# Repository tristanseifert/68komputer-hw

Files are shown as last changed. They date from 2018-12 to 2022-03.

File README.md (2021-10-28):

# 68komputer Hardware
Hardware designs for the 68komputer.

You can find the related software [in this repository.](https://github.com/tristanseifert/68komputer-sw)

## Old stuff
The 68008-based design I [wrote about](https://blraaz.me/hardware/2019/11/01/68komputer-it-lives.html) and some other stuff has been moved to the `old` directory. Unfortunately, those designs were done using Cadsoft EAGLE, and I no longer have access to my license for it. There are likely hardware bugs I have no way of fixing. Yay!

## License
The contents of this repo are available under the ISC license.

Previously, the material in the `old` directory was BSD licensed; you can continue to use it under the terms of this license.

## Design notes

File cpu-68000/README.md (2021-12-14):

# 68000 CPU Board
This directory contains the schematic and board files for the main 68komputer CPU board, based around a 68000 operating at up to 10MHz. It combines the processor with 1M of RAM and flash ROM and some additional peripherals.

## Peripherals
In addition to the megabyte of boot ROM and RAM available on the board, the following peripherals are available:

- 32K of battery backed NVRAM, which includes a phantom RTC for time keeping
- An [XR68C681](https://www.maxlinear.com/product/interface/uarts/8-bit-vlio-uarts/xr68c681) DUART, compatible with the "legacy" Motorola 68681 part
- I²C master provided by a [PCF8584](https://www.nxp.com/products/interfaces/ic-spi-serial-interface-devices/ic-bus-controller-and-bridge-ics/ic-bus-controller:PCF8584) controller. It's used to access the I2C bus on the backplane.
- Dual SAA1099 PSG audio chips

## Backplane Interface
The backplane interface is just a buffered copy of the 68k's address and data bus, as well as many of its control signals. The direction of buffers on the CPU board are automatically controlled taking into account external bus masters.

As long as external bus masters properly implement the 68000 bus mastering, they will be entirely transparent. All read/write transactions to peripherals implemented on the CPU board itself will be broadcast on the backplane bus to allow external debugging hardware to capture these accesses.

## Programmable Logic
Many of the logic parts of the system are implemented in 22V10C GALs. See the `logic` directory for these files. They can be assembled using [galette.](https://github.com/simon-frankau/galette)

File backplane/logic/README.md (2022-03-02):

# Backplane Logic Equations
This directory contains the GAL logic equations for the backplane. These are meant to be assembled using [Galette](https://github.com/simon-frankau/galette) assembler.

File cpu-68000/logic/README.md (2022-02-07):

# CPU Board Logic Equations
Here are the GAL logic equations for the CPU board. Filenames map to component names in the rev 2 board/schematic as follows:

- U102: addr_decode.pld
- U305: m68k.pld

** TODO ** It remains to be seen whether most of these logic equations are actually correct; since galette doesn't do parenthesis for grouping of individual components it might all be wrong. Whoops

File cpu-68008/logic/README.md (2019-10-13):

# Logic Files
Source for the GALs on the board is provided in this directory. Below is an overall summary of all signals in the system.

## Inputs
### CPU
- FC[2..0]: Function code
- A[15..19]: Address bus
- !AS: Indicates that the address bus contains a valid address
- R/!W!: Sets the bus direction, valid with !AS

### External Bus
- !BUS_IRQ: External interrupt request
- !BUS_DTACK: Bus data acknowledge

### Peripherals
- !68681_IRQ: DUART interrupt request
- !68681_DTACK: DUART data acknowledge

### Miscellaneous
- RESET: Active high system reset

## Internal Signals
- ADDR_DECODE: Asserted when we're decoding a regular address
	- `!(FC0 & FC1 & FC2) & AS`
- IACK: Asserted when the bus cycle is an interrupt acknowledge
	- `(FC0 & FC1 & FC2) & (A19 & A18 & A17 & A16)`

## Outputs
### CPU
- !VPA: Used to indicate autovectoring in response to IACK
	- `IACK`
- !IPL0/2, !IPL1: Highest priority pending interrupt
- !HALT: Halts the CPU; always asserted with !RESET when RESET is asserted
- !RESET: CPU reset (open drain)
- !BERR: Asserts a bus error if no device asserts DTACK
- !DTACK: Asserts data is ready
	- `68681_DTACK | BUS_DTACK | ROM_CS | RAM_CS | RTC_CS`

### External Bus
- !BUS_CS: Selects the external bus peripherals
	- `ADDR_DECODE & ()`

### Peripherals
- !OE: Output enables for ROM/RAM
	- `!(R/!W!)`
- !68681_IACK: Asserted in response to an interrupt acknowledge for DUART (not used)
- !68681_CS: DUART chip select
	- `ADDR_DECODE & (!A19 & !A18 & A17 & !A17 & !A15)
- !ROM_CS: ROM chip select
	- `ADDR_DECODE & (!A19 & !A18 & !A17)`
- !RAM_CS: RAM chip select
	- `ADDR_DECODE & A19`
- !RTC_CS: NVRAM/RTC chip select
	- `ADDR_DECODE & (!A19 & !A18 & A17 & !A16 & A15)`

### Miscellaneous
- !BERR_TIMER_CLR: Clear signal for bus error timeout generator, this is basically !AS

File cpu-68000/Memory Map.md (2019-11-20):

- $000000 - $0FFFFF: On-Board RAM
	- Remapped as Boot ROM if REMAP is asserted
- $100000 - $7FFFFF: Reserved for RAM expansion
- $800000 - $DFFFFF: Reserved for external peripherals
- $E00000 - $EFFFFF: Boot ROM
- $F00000 - $FFFFFF: Peripherals
	- $F00000 - $F7FFFF: Reserved for external peripherals
	- $FF0000 - $FF7FFF: 68681 (DUART)
	- $FF8000 - $FFFFFF: DS1244 (RTC/NVRAM)

Spaces from $100000 - $DFFFFF and $F00000 - $FEFFFF can be used by expansion connected via SV101. 

**Note:** /DTACK is provided only for addresses decoded internally, e.g. peripherals must provide their own /DTACK.

## Boot ROM Remap
Remapping of boot ROM is configured by OP2 (pin 31) of the 68681. When high (the reset state) the ROM will be mapped at the base of the address space. The boot ROM would disable this line, copy the vector table to RAM, which makes this remap completely transparent to programs on the machine.

## Peripherals
External peripherals will typically occupy an entire megabyte of address space to simplify address decoding; these peripherals will receive an additional 64K segment in IO space for configuration registers.

For an external peripheral at address $800000, the first 64K segment from $F00000 - $F0FFFF would be reserved; a peripheral at address $900000 the segment $F10000 - $F1FFFF, and so forth up to $D00000 receiving the segment $F50000 - $F5FFFF. Note that this rule applies only to peripherals that occupy an entire megabyte in the address space.

Peripherals may elect to only occupy IO space, in which case they must stay in the range of $F60000 - $F7FFFF.

### Identification ROMs
The expansion connector contains the /EXT_ID signal on pin 41. When asserted, expansion cards with info ROMs will map their ROMs onto the bus, instead of whatever they normally would.

Such a ROM must be on 32K boundaries, and contain a specific signature for the system to discover it. The ROM must be connected to the low byte (D0..D7) of the data bus, and will be shadowed to the highest area of RAM and run from there.

/EXT_ID is driven by OP6 (pin 29) of the 68681.

### Interrupts
To assert a CPU interrupt, peripherals may assert either /INTA or /INTB lines. Two IRQ lines are provided to reduce the complexity of interrupt handler routines.

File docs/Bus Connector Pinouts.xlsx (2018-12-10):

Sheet: Pinouts
External Bus Interface (68000) |  |  |  | External Bus Interface (68030) |  |  |  | Expansion Card Interface
Column | Row A | Row B | Row C | Column | Row A | Row B | Row C | Column | Row A | Row B | Row C
1 | GND | 5V | D0 | 1 | A0 | 5V | D0 | 1 | 3V3 | 3V3 | /RESET
2 | A1 | 5V | D1 | 2 | A1 | 5V | D1 | 2 | 3V3 | 3V3
3 | A2 | 5V | D2 | 3 | A2 | 5V | D2 | 3 | GND | GND | GND
4 | A3 | Reserved | D3 | 4 | A3 | /CBREQ | D3 | 4 | GND | GND | GND
5 | A4 | Reserved | D4 | 5 | A4 | /OCS | D4 | 5
6 | A5 | FC[0] | D5 | 6 | A5 | FC[0] | D5 | 6 | AD[1] | GND | AD[0]
7 | A6 | FC[1] | D6 | 7 | A6 | FC[1] | D6 | 7 | AD[3] | GND | AD[2]
8 | A7 | FC[2] | D7 | 8 | A7 | FC[2] | D7 | 8 | AD[5] | GND | AD[4]
9 | A8 | /BERR | D8 | 9 | A8 | /BERR | D8 | 9 | AD[7] | GND | AD[6]
10 | A9 | /RESET | D9 | 10 | A9 | /RESET | D9 | 10 | AD[9] | GND | AD[8]
11 | A10 | /HALT | D10 | 11 | A10 | /HALT | D10 | 11 | AD[11] | GND | AD[10]
12 | A11 | /VPA | D11 | 12 | A11 | /CBACK | D11 | 12 | AD[13] | GND | AD[12]
13 | A12 | /BR | D12 | 13 | A12 | /BR | D12 | 13 | AD[15] | GND | AD[14]
14 | A13 | /BG | D13 | 14 | A13 | /BG | D13 | 14 | AD[17] | GND | AD[16]
15 | A14 | /BGACK | D14 | 15 | A14 | /BGACK | D14 | 15 | AD[19] | GND | AD[18]
16 | A15 | Reserved | D15 | 16 | A15 | /ECS | D15 | 16 | AD[21] | GND | AD[20]
17 | A16 | /IRQ | D16 | 17 | A16 | /IRQ | D16 | 17 | AD[23] | GND | AD[22]
18 | A17 | Reserved | Reserved | 18 | A17 | /STERM | D17 | 18 | AD[25] | GND | AD[24]
19 | A18 | Reserved | Reserved | 19 | A18 | /RMC | D18 | 19 | AD[27] | GND | AD[26]
20 | A19 | Reserved | Reserved | 20 | A19 | /DS | D19 | 20 | AD[29] | GND | AD[28]
21 | A20 | /AS | Reserved | 21 | A20 | /AS | D20 | 21 | AD[31] | GND | AD[30]
22 | A21 | R/W | Reserved | 22 | A21 | R/W | D21 | 22 | GND | GND
23 | A22 | /UDS | Reserved | 23 | A22 | SIZ[0] | D22 | 23 | GND | GND
24 | A23 | /LDS | Reserved | 24 | A23 | SIZ[1] | D23 | 24 |  |  | MODE[0]
25 | GND | GND | Reserved | 25 | A24 | GND | D24 | 25 | CONFIG |  | MODE[1]
26 | GND | CLK | Reserved | 26 | A25 | CLK | D25 | 26 | CS[1] |  | CS[0]
27 | GND | GND | Reserved | 27 | A26 | GND | D26 | 27 | CS[3] |  | CS[2]
28 | GND | /DTACK | Reserved | 28 | A27 | /DSACK[0] | D27 | 28 | /ACK | 32BIT | /START
29 | GND | Reserved | Reserved | 29 | A28 | /DSACK[1] | D28 | 29 | 5V | 5V | 5V
30 | GND | GND | Reserved | 30 | A29 | GND | D29 | 30 | 5V | 5V | 5V
31 | GND | GND | Reserved | 31 | A30 | GND | D30 | 31 | /IRQREQ | GND | GND
32 | GND | GND | Reserved | 32 | A31 | GND | D31 | 32 | /IRQACK | GND | CLK
Note: Reserved lines should be left floating.

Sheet: Signal descriptions
Signal Descriptions
Signal | Description
/RESET | Bus reset: asserted to reset all peripherals back into their initial states, aborting any in-progress transactions.
/START | Asserted when a transactions starts, aka when the AD lines contain a valid address.
/ACK | Acknowledges reception of address: on the next clock, the AD lines become data lines for the read/write.
CS[0..3] | Binary encoded chip select for one of 15 cards. This is decoded into individual lines for each slot by the backplane.
MODE[0..1] | Bus mode, dependant on the phase the transaction is in: Start mode: 00 = Read, 01 = Reserved, 10 = Write, 11 = Reserved Transfer mode: 00 = NACK, 01 = Reserved, 10 = bus error, 11 = Transfer complete IRQ acknowledge cycle: Always 00
CONFIG | Asserted when accessing a card's configuration space.
/IRQREQ | Asserted by a peripheral card to cause an interrupt. The card should wait for /IRQACK, then when selected, put its interrupt vector on the bus.
/IRQACK | Asserted by the bus controller to respond to an interrupt. When a card is selected and this signal is asserted, it places its interrupt vector number on the low 8 bits of the bus.
AD[0..31] | 32-bit multiplexed address/data bus.
32BIT | Indicates whether the system can perform 32-bit data operations when high (+3V3)

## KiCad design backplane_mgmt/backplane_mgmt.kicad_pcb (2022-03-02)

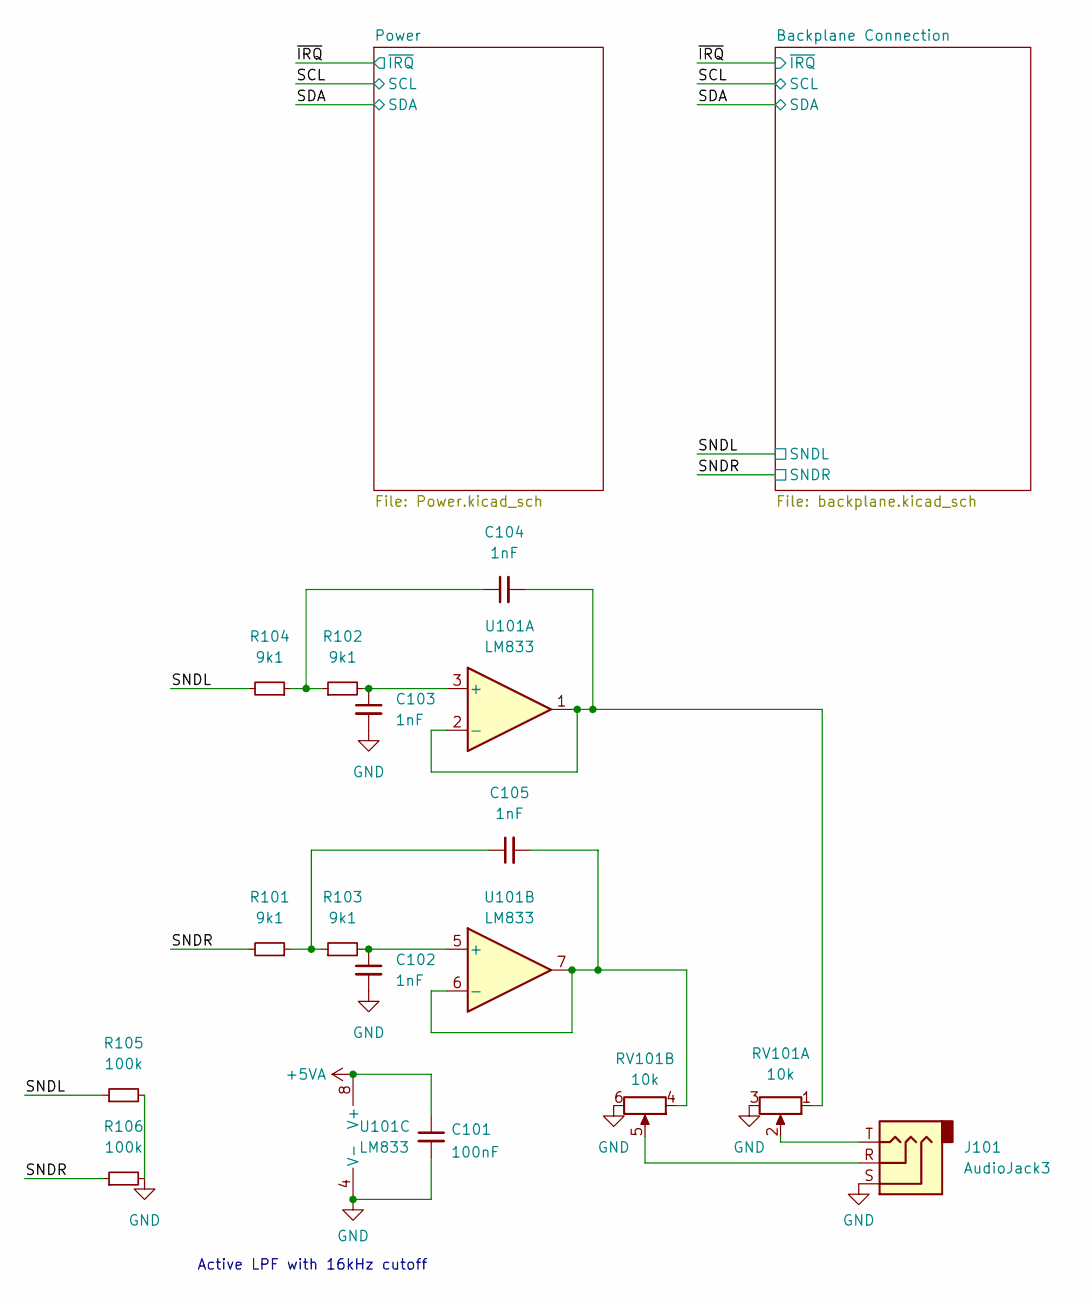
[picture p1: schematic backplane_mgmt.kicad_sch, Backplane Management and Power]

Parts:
C101: 100nF; C_0805_2012Metric
C102, C103, C104, C105: 1nF; C_Rect_L7.2mm_W2.5mm_P5.00mm_FKS2_FKP2_MKS2_MKP2; MPN B32529C1102J
J101: AudioJack3; Jack_3.5mm_CUI_SJ1-3533NG_Horizontal; MPN SJ1-3533NG
R101, R102, R103, R104: 9k1; R_0805_2012Metric
R105, R106: 100k; R_0805_2012Metric
RV101: 10k; Potentiometer_Alps_RK097_Dual_Horizontal
U101: LM833; DIP-8_W7.62mm_Socket

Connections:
+5VA: C101.1, U101.8 (V+); also elsewhere on the board
/SNDL: R104.2, R105.1; also elsewhere on the board
/SNDR: R101.2, R106.1; also elsewhere on the board
GND: C101.2, C102.2, C103.2, J101.S, R105.2, R106.2, RV101.3, RV101.6, U101.4 (V-); also elsewhere on the board
unnamed: C102.1, R103.2, U101.5 (+)
unnamed: C103.1, R102.2, U101.3 (+)
unnamed: C104.1, R102.1, R104.1
unnamed: C104.2, RV101.1, U101.1, U101.2 (-)
unnamed: C105.1, R101.1, R103.1
unnamed: C105.2, RV101.4, U101.6 (-), U101.7
unnamed: J101.R, RV101.5
unnamed: J101.T, RV101.2

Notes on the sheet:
Active LPF with 16kHz cutoff

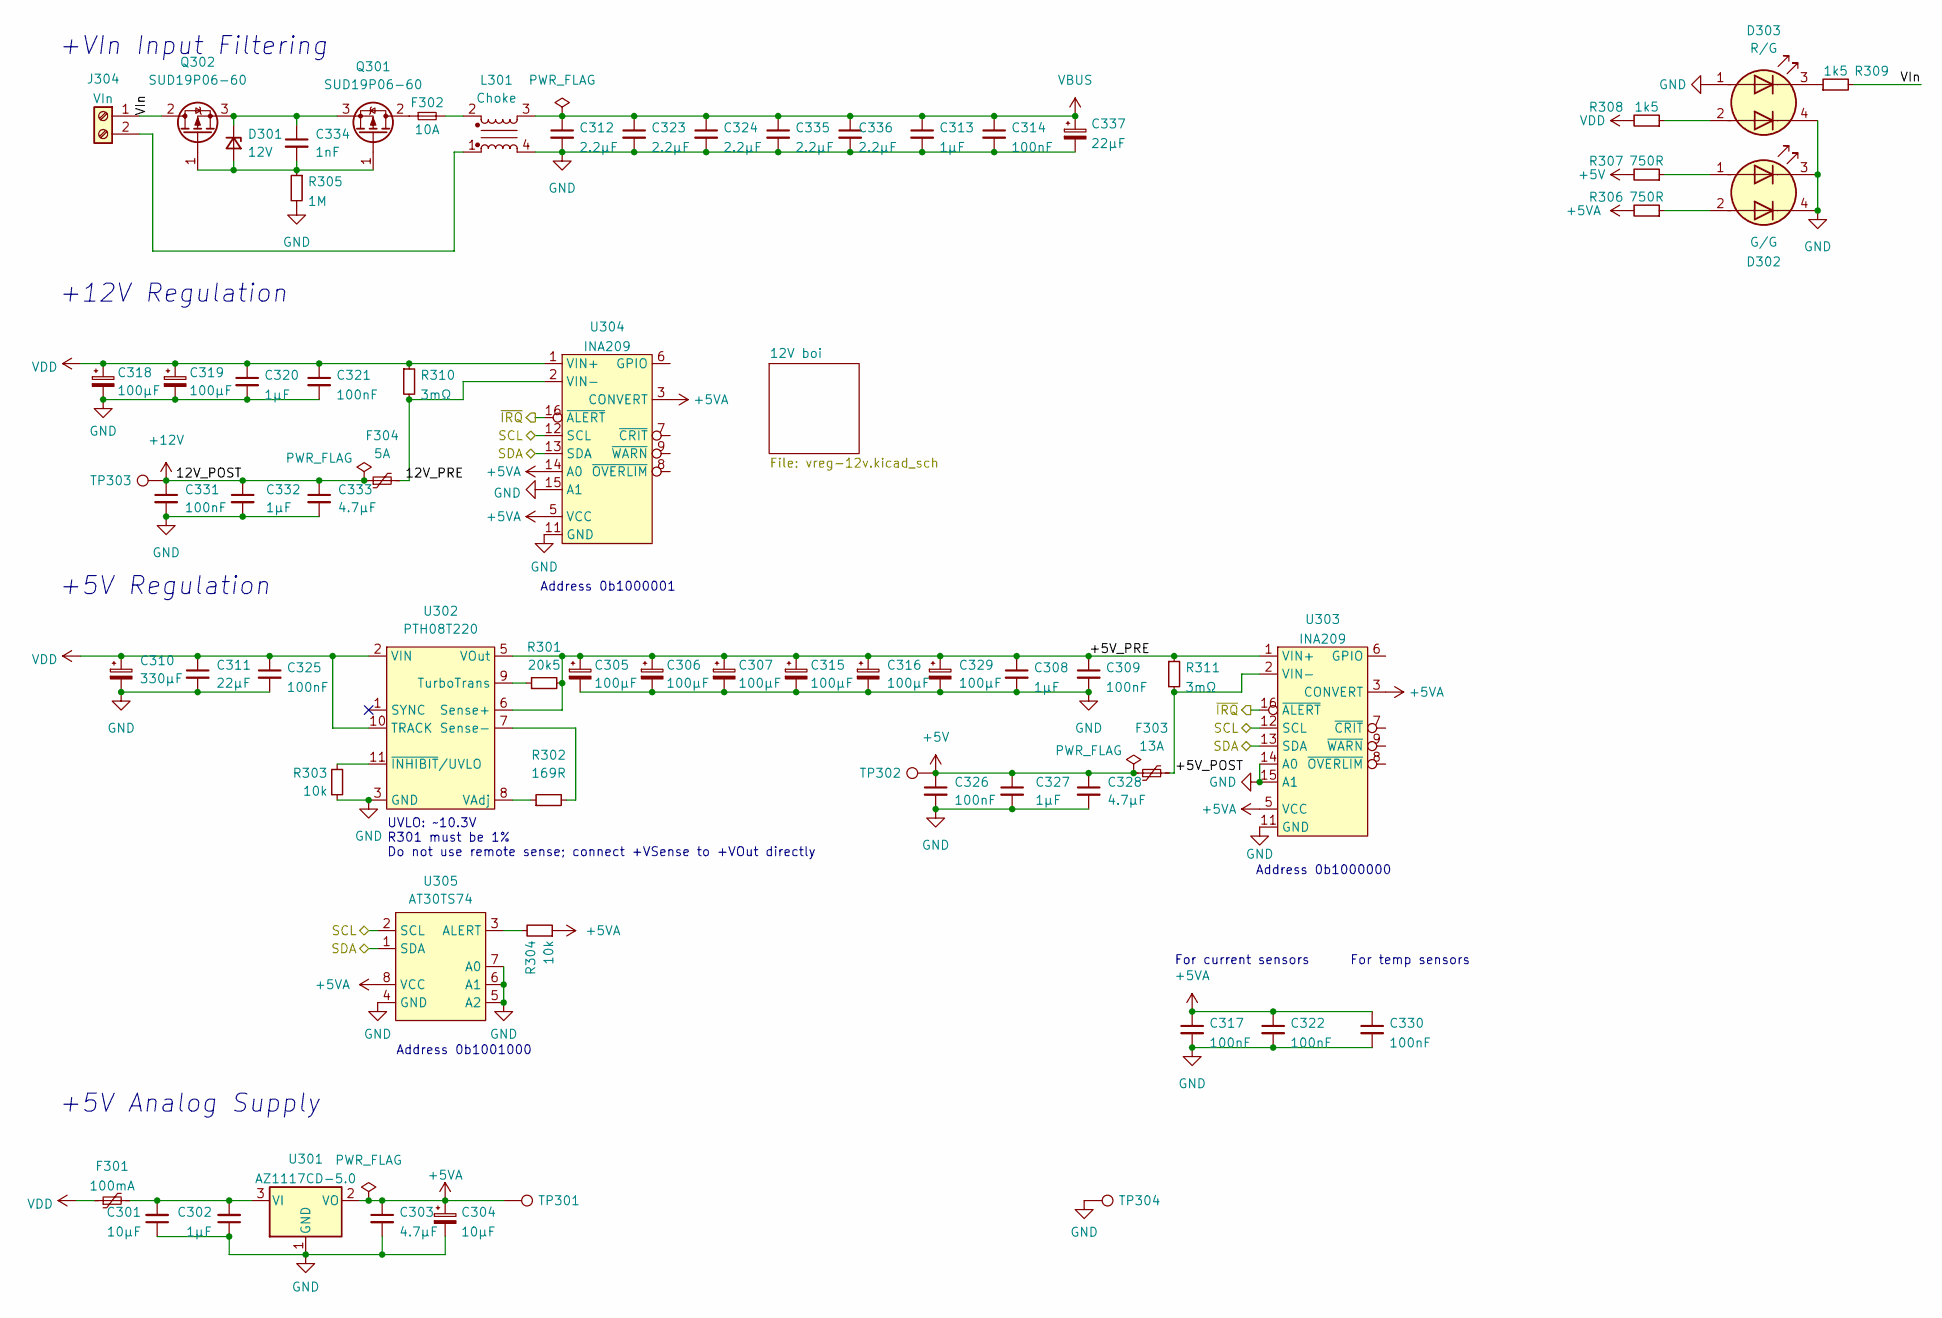
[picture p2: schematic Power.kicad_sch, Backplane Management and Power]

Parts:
C301: 10µF; C_0805_2012Metric
C302, C308, C313, C320, C327, C332: 1µF; C_0805_2012Metric
C303, C328, C333: 4.7µF; C_0805_2012Metric
C304: 10µF; CP_EIA-3216-18_Kemet-A; MPN TAJA106K016RNJV
C305, C306, C307, C315, C316, C329: 100µF; CP_Radial_D5.0mm_P2.00mm; MPN A750BK107M1AAAE024
C309, C314, C317, C321, C322, C325, C326, C330, C331: 100nF; C_0805_2012Metric
C310: 330µF; CP_Radial_D8.0mm_P3.50mm; MPN A750KS337M1EAAE018
C311: 22µF; C_0805_2012Metric; MPN CL21A226MAQNNNF
C312, C323, C324, C335, C336: 2.2µF; C_1206_3216Metric; MPN CL31A225KB9LNNC
C318, C319: 100µF; CP_Radial_D8.0mm_P3.50mm; MPN A750KK107M1EAAE040
C334: 1nF; C_0805_2012Metric
C337: 22µF; CP_Radial_D5.0mm_P2.00mm
D301: 12V; D_MiniMELF; MPN ZMM5242B
D302: G/G; H201Cxx; MPN H201CGDL
D303: R/G; H201Cxx; MPN H201CGHDL
F301: 100mA; Fuse_1812_4532Metric; MPN PTS181230V010
F302: 10A; Keystone-3557-2-0; MPN 3557-10
F303: 13A; Fuse_Bourns_MF-RHT1300; MPN MF-RHT1300-0
F304: 5A; Fuse_Bourns_MF-RHT500; MPN MF-RHT500-2
J304: VIn; CUI_TBP01R1W-508-02BE; MPN TBP01R1W-508-02BE
L301: Choke; TDK-ACM1513-0-0-MFG; MPN ACM1513-551-2PL-TLHF
Q301, Q302: SUD19P06-60; TO-252-2; MPN SUD19P06-60-GE3
R301: 20k5; R_0805_2012Metric
R302: 169R; R_0805_2012Metric
R303, R304: 10k; R_0805_2012Metric
R305: 1M; R_0805_2012Metric
R306, R307: 750R; R_0805_2012Metric
R308, R309: 1k5; R_0805_2012Metric
R310, R311: 3mΩ; R_2512_6332Metric_Pad1.40x3.35mm_HandSolder; MPN LRMAP2512-R003FT4
TP301: +5VA; TestPoint_Loop_D2.60mm_Drill1.4mm_Beaded; MPN 534-5001
TP302: +5V; TestPoint_Loop_D2.60mm_Drill1.4mm_Beaded; MPN 534-5001
TP303: +12V; TestPoint_Loop_D2.60mm_Drill1.4mm_Beaded; MPN 534-5001
TP304: GND; TestPoint_Loop_D2.60mm_Drill1.4mm_Beaded; MPN 534-5001
U301: AZ1117CD-5.0; TO-252-2
U302: PTH08T220; Texas_Instruments-PTH08T220WAD-Manufacturer_Recommended
U303, U304: INA209; TSSOP-16_4.4x5mm_P0.65mm
U305: AT30TS74; MSOP-8_3x3mm_P0.65mm

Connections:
+5V: C326.1, C327.1, C328.1, F303.1, R307.2, TP302.1; also elsewhere on the board
+5VA: C303.1, C304.1, C317.1, C322.1, C330.1, R304.1, R306.2, TP301.1, U301.2 (VO), U303.3 (CONVERT), U303.5 (VCC), U303.10 (VCC), U304.3 (CONVERT), U304.5 (VCC), U304.10 (VCC), U304.14 (A0), U305.8 (VCC); also elsewhere on the board
+12V: C331.1, C332.1, C333.1, F304.1, TP303.1; also elsewhere on the board
/Power/12V_PRE: F304.2, R310.2, U304.2 (VIN-)
/Power/+5V_POST: F303.2, R311.2, U303.2 (VIN-)
/Power/+5V_PRE: C305.1, C306.1, C307.1, C308.1, C309.1, C315.1, C316.1, C329.1, R301.2, R311.1, U302.5 (VOut), U302.6 (Sense+), U303.1 (VIN+)
/Power/VIn: J304.1, Q302.2 (D), R309.2
/SCL: U303.12 (SCL), U304.12 (SCL), U305.2 (SCL); also elsewhere on the board
/SDA: U303.13 (SDA), U304.13 (SDA), U305.1 (SDA); also elsewhere on the board
/~IRQ: U303.16 (~ALERT), U304.16 (~ALERT); also elsewhere on the board
GND: C301.1, C302.1, C303.2, C304.2, C305.2, C306.2, C307.2, C308.2, C309.2, C310.2, C311.2, C312.2, C313.2, C314.2, C315.2, C316.2, C317.2, C318.2, C319.2, C320.2, C321.2, C322.2, C323.2, C324.2, C325.2, C326.2, C327.2, C328.2, C329.2, C330.2, C331.2, C332.2, C333.2, C335.2, C336.2, C337.2, D302.3 (K1), D302.4 (K2), D303.1 (A1), D303.4 (K2), L301.4, R303.1, R305.2, TP304.1, U301.1 (GND), U302.3 (GND), U302.4 (GND), U303.4 (GND), U303.11 (GND), U303.14 (A0), U303.15 (A1), U304.4 (GND), U304.11 (GND), U304.15 (A1), U305.4 (GND), U305.5 (A2), U305.6 (A1), U305.7 (A0); also elsewhere on the board
unnamed: C301.2, C302.2, F301.2, U301.3 (VI)
unnamed: C334.1, D301.1 (K), Q301.3 (S), Q302.3 (S)
unnamed: C334.2, D301.2 (A), Q301.1 (G), Q302.1 (G), R305.1
unnamed: D302.1 (A1), R307.1
unnamed: D302.2 (A2), R306.1
unnamed: D303.2 (A2), R308.1
unnamed: D303.3 (K1), R309.1
unnamed: F302.1, Q301.2 (D)
unnamed: F302.2, L301.2
unnamed: J304.2, L301.1
unnamed: R301.1, U302.9 (TurboTrans)
unnamed: R302.1, U302.8 (VAdj)
unnamed: R302.2, U302.7 (Sense-)
unnamed: R303.2, U302.11 (~INHIBIT/UVLO)
unnamed: R304.2, U305.3 (ALERT)
VBUS: C312.1, C313.1, C314.1, C323.1, C324.1, C335.1, C336.1, C337.1, L301.3; also elsewhere on the board
VDD: C310.1, C311.1, C318.1, C319.1, C320.1, C321.1, C325.1, F301.1, R308.2, R310.1, U302.2 (VIN), U302.10 (TRACK), U304.1 (VIN+); also elsewhere on the board

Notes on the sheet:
+5V Regulation
Address 0b1000000
+12V Regulation
Address 0b1001000
+5V Analog Supply
Address 0b1000001
For temp sensors
UVLO: ~10.3V R301 must be 1% Do not use remote sense; connect +VSense to +VOut directly
+VIn Input Filtering
For current sensors

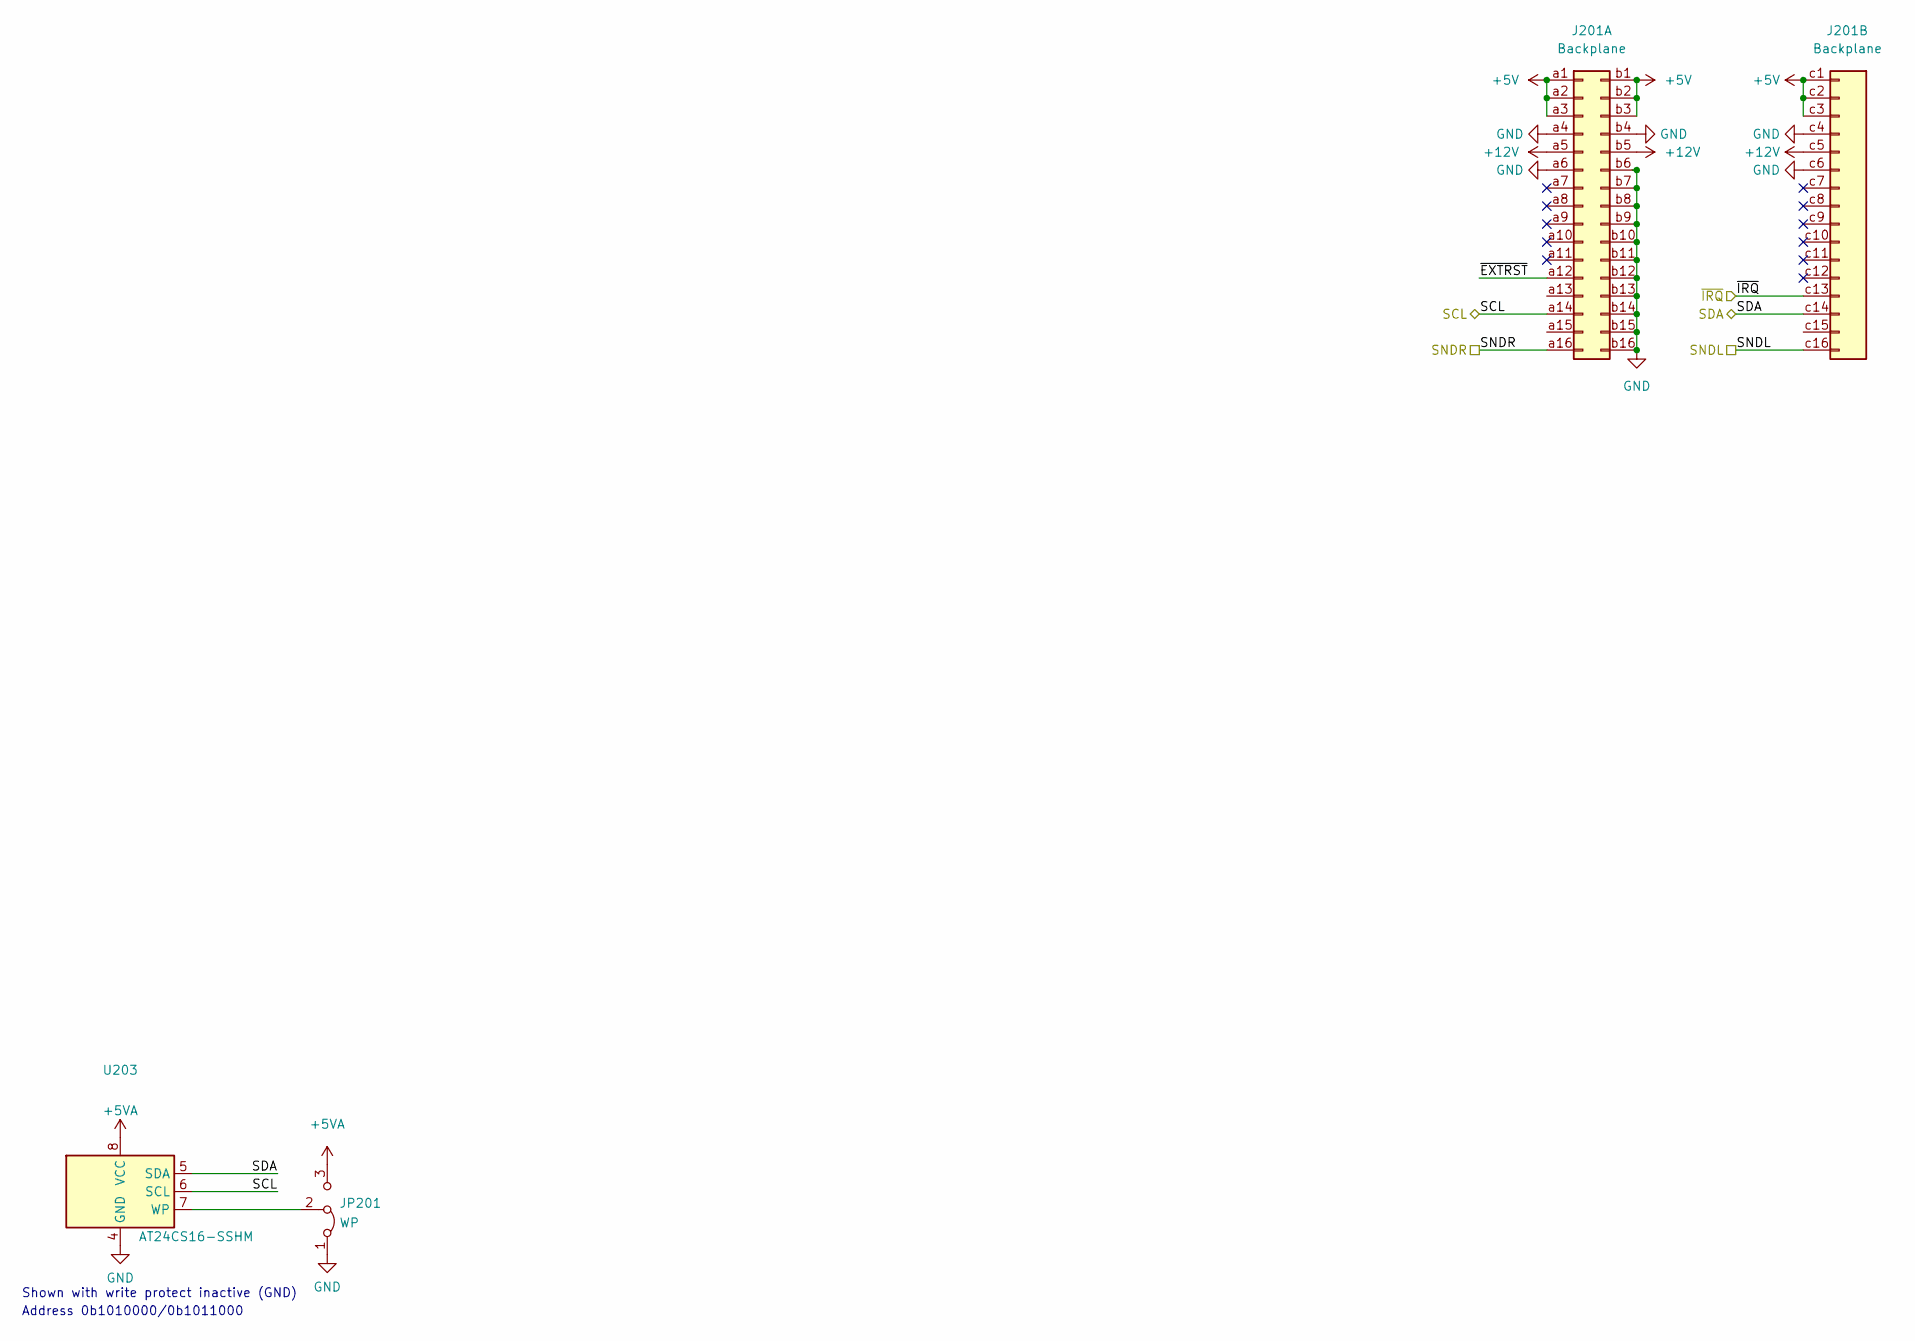
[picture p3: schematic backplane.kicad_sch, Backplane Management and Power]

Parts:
J201: Backplane; DIN41612_C2_3x16_Male_Horizontal_THT
JP201: WP; SolderJumper-3_P1.3mm_Bridged2Bar12_Pad1.0x1.5mm
U203: AT24CS16-SSHM; SOIC-8_3.9x4.9mm_P1.27mm; MPN AT24CS32-SSHM-T

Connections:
+5V: J201.a1, J201.a2, J201.a3, J201.b1, J201.b2, J201.b3, J201.c1, J201.c2, J201.c3; also elsewhere on the board
+5VA: JP201.3 (B), U203.8 (VCC); also elsewhere on the board
+12V: J201.a5, J201.b5, J201.c5; also elsewhere on the board
/Backplane Connection/~EXTRST: J201.a12
/SCL: J201.a14, U203.6 (SCL); also elsewhere on the board
/SDA: J201.c14, U203.5 (SDA); also elsewhere on the board
/SNDL: J201.c16; also elsewhere on the board
/SNDR: J201.a16; also elsewhere on the board
/~IRQ: J201.c13; also elsewhere on the board
GND: J201.a4, J201.a6, J201.b4, J201.b6, J201.b7, J201.b8, J201.b9, J201.b10, J201.b11, J201.b12, J201.b13, J201.b14, J201.b15, J201.b16, J201.c4, J201.c6, JP201.1 (A), U203.4 (GND); also elsewhere on the board
unnamed: JP201.2 (C), U203.7 (WP)

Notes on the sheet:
Shown with write protect inactive (GND)
Address 0b1010000/0b1011000

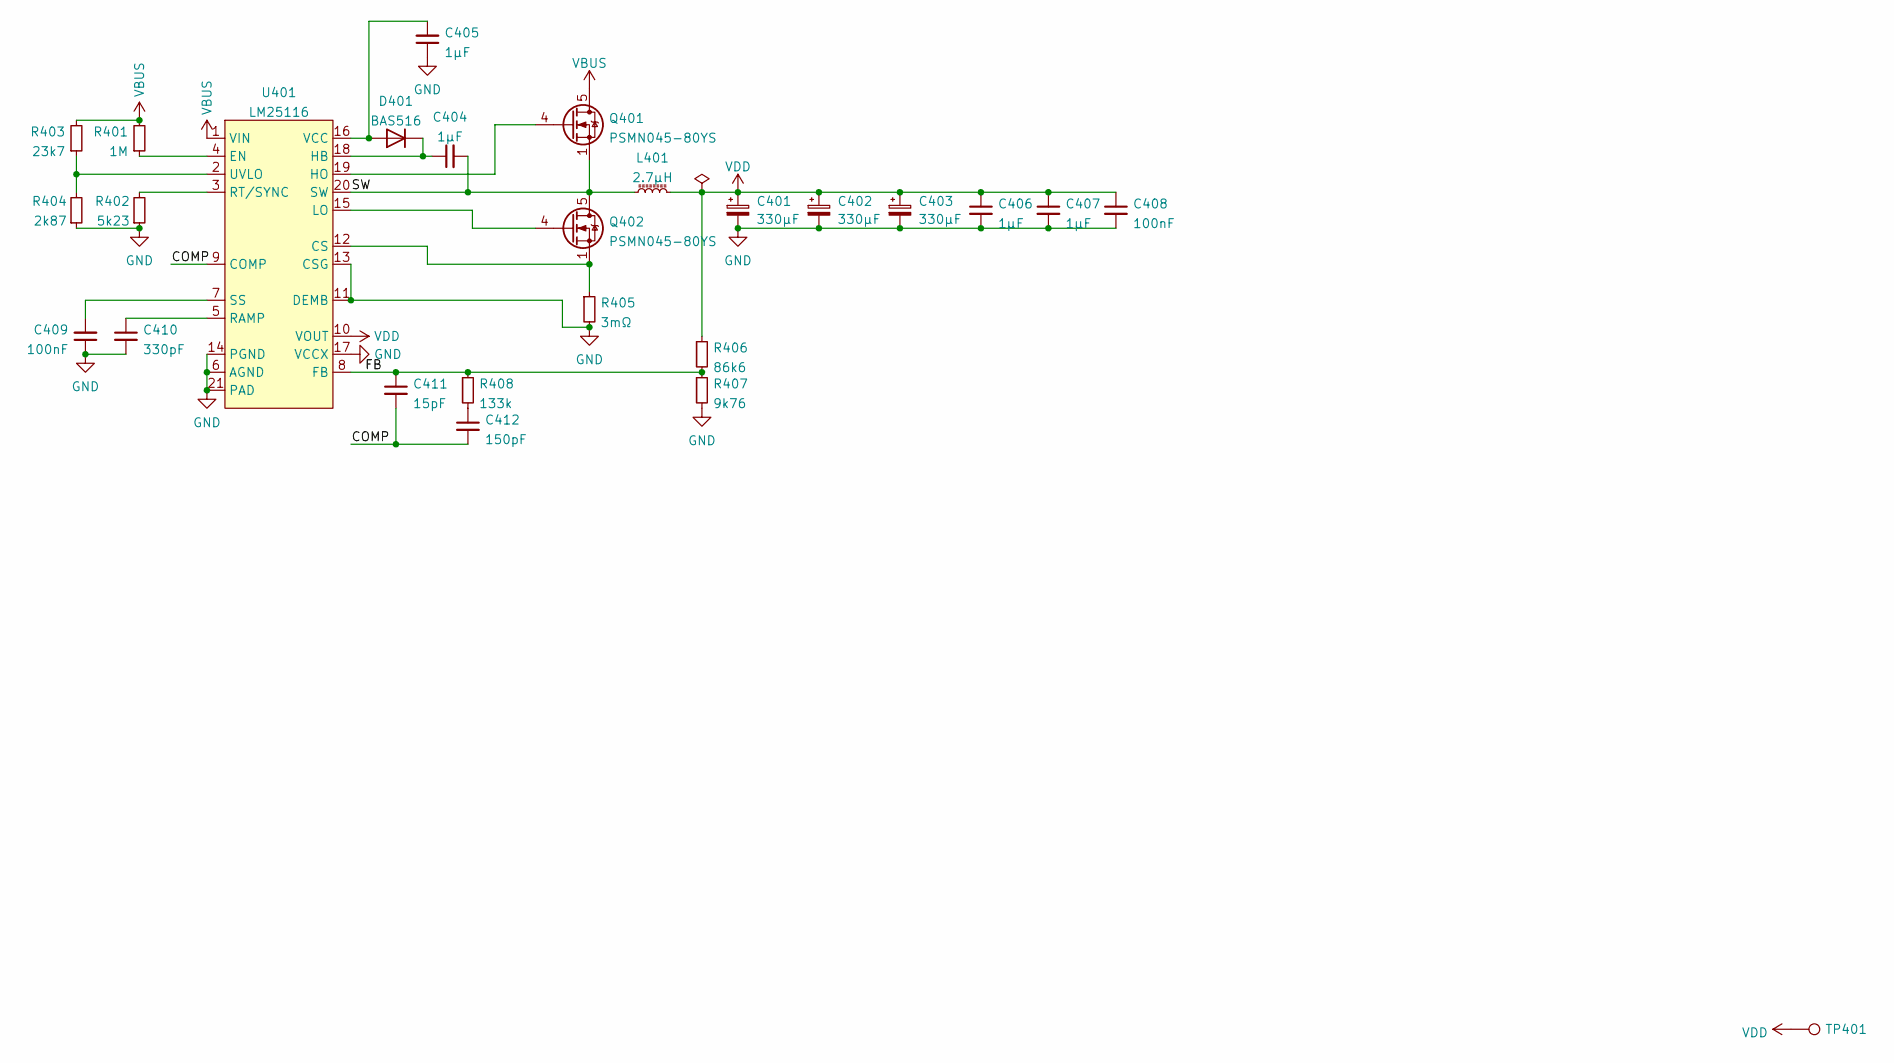
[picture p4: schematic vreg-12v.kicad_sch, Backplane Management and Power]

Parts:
C401, C402, C403: 330µF; CP_Radial_D8.0mm_P3.50mm; MPN 860010474012
C404, C405, C406, C407: 1µF; C_0805_2012Metric
C408, C409: 100nF; C_0805_2012Metric
C410: 330pF; C_0805_2012Metric
C411: 15pF; C_0805_2012Metric; MPN 885012007052
C412: 150pF; C_0805_2012Metric; MPN 885012207081
D401: BAS516; D_SOD-523; MPN BAS516-TP
L401: 2.7µH; Bourns_Inc.-SRP1250-0-0-MFG; MPN SRP1250-2R7M
Q401, Q402: PSMN045-80YS; LFPAK56; MPN PSMN045-80YS,115
R401: 1M; R_0805_2012Metric
R402: 5k23; R_0805_2012Metric; MPN CR0805-FX-5231ELF
R403: 23k7; R_0805_2012Metric; MPN CR0805-FX-5231ELF
R404: 2k87; R_0805_2012Metric; MPN CR0805-FX-5231ELF
R405: 3mΩ; R_2512_6332Metric_Pad1.40x3.35mm_HandSolder; MPN LRMAP2512-R003FT4
R406: 86k6; R_0805_2012Metric; MPN RC0805FR-0786K6L
R407: 9k76; R_0805_2012Metric; MPN RC0805FR-079K76L
R408: 133k; R_0805_2012Metric
TP401: VDD; TestPoint_Loop_D2.60mm_Drill1.4mm_Beaded; MPN 534-5001
U401: LM25116; HTSSOP-20-1EP_4.4x6.5mm_P0.65mm_EP2.85x4mm

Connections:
/Power/12V boi/COMP: C411.2, C412.2, U401.9 (COMP)
/Power/12V boi/FB: C411.1, R406.2, R407.1, R408.1, U401.8 (FB)
/Power/12V boi/SW: C404.2, L401.1, Q401.1 (S), Q401.2 (S), Q401.3 (S), Q402.5 (D), U401.20 (SW)
GND: C401.2, C402.2, C403.2, C405.1, C406.2, C407.2, C408.2, C409.1, C410.2, R402.1, R404.1, R405.2, R407.2, U401.6 (AGND), U401.11 (DEMB), U401.13 (CSG), U401.14 (PGND), U401.17 (VCCX), U401.21 (PAD); also elsewhere on the board
unnamed: C404.1, D401.1 (K), U401.18 (HB)
unnamed: C405.2, D401.2 (A), U401.16 (VCC)
unnamed: C409.2, U401.7 (SS)
unnamed: C410.1, U401.5 (RAMP)
unnamed: C412.1, R408.2
unnamed: Q401.4 (G), U401.19 (HO)
unnamed: Q402.1 (S), Q402.2 (S), Q402.3 (S), R405.1, U401.12 (CS)
unnamed: Q402.4 (G), U401.15 (LO)
unnamed: R401.1, U401.4 (EN)
unnamed: R402.2, U401.3 (RT/SYNC)
unnamed: R403.1, R404.2, U401.2 (UVLO)
VBUS: Q401.5 (D), R401.2, R403.2, U401.1 (VIN); also elsewhere on the board
VDD: C401.1, C402.1, C403.1, C406.1, C407.1, C408.1, L401.2, R406.1, TP401.1, U401.10 (VOUT); also elsewhere on the board

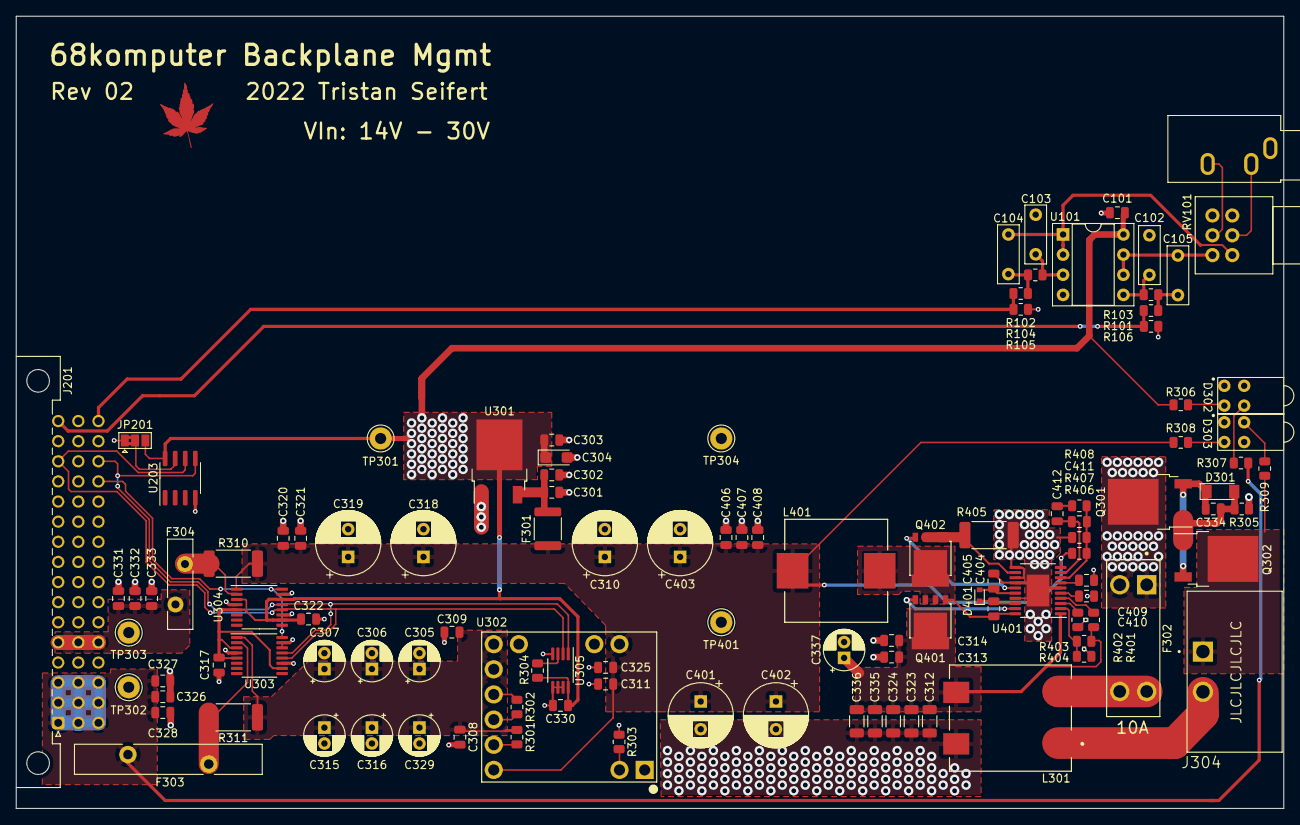
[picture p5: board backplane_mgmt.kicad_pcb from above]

Board: 2 copper layers, 160.0 x 100.0 mm, 111 parts (0 on the bottom side), 53 nets.

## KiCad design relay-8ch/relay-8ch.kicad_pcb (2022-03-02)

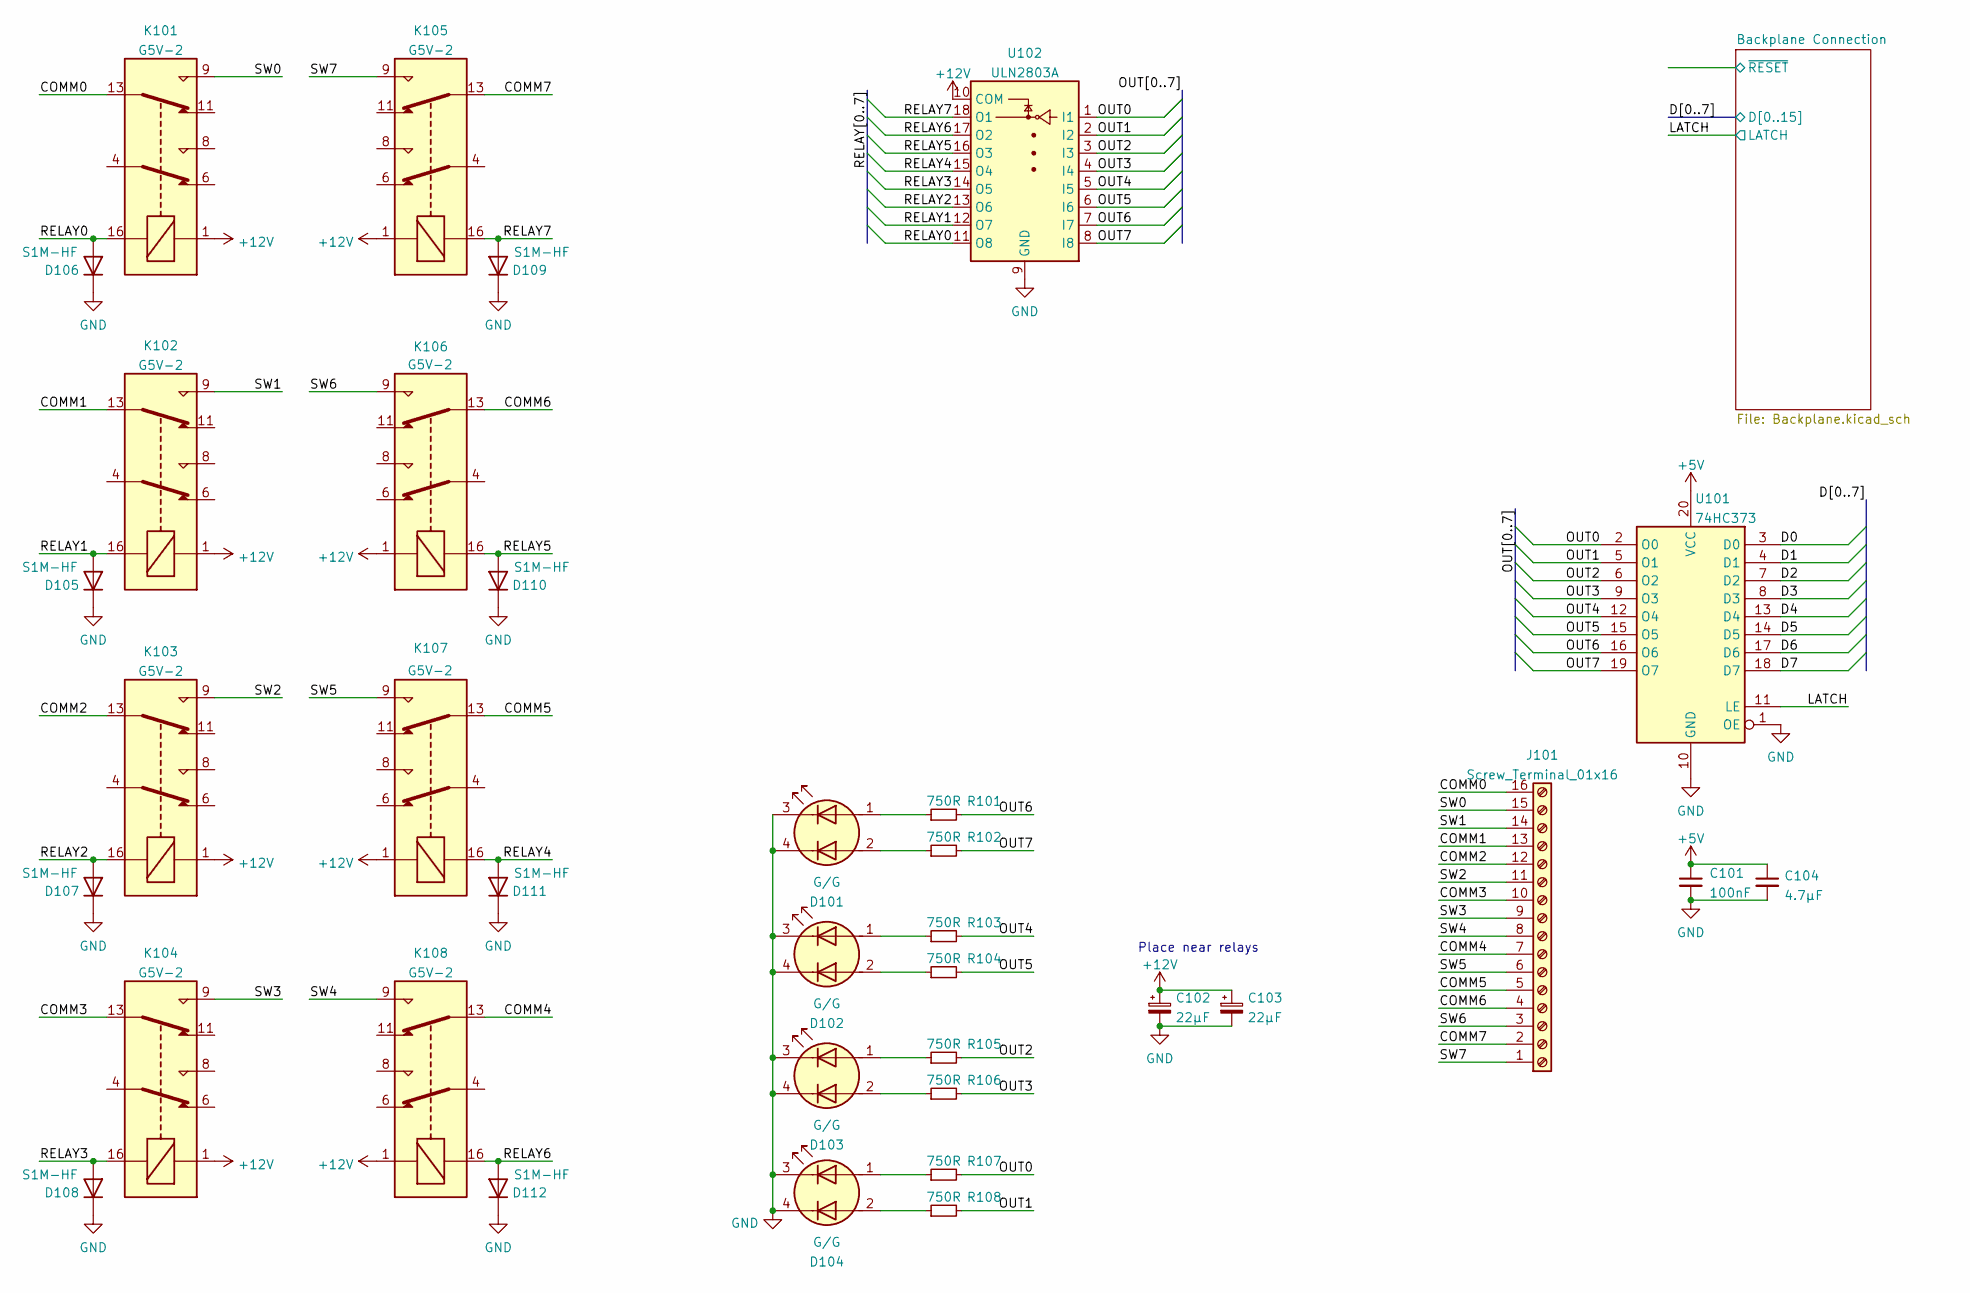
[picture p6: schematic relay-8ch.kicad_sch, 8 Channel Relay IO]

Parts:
C101: 100nF; C_0805_2012Metric
C102, C103: 22µF; CP_Radial_D6.3mm_P2.50mm; MPN A759EK226M1JAAE054
C104: 4.7µF; C_0805_2012Metric
D101, D102, D103, D104: G/G; H201Cxx; MPN H201CGDL
D105, D106, D107, D108, D109, D110, D111, D112: S1M-HF; D_SMA; MPN S1M-HF
J101: Screw_Terminal_01x16; CUI_TBP02R1W-381-16BE; MPN TBP02R1W-381-16BE
K101, K102, K103, K104, K105, K106, K107, K108: G5V-2; Relay_DPDT_Omron_G5V-2
R101, R102, R103, R104, R105, R106, R107, R108: 750R; R_0805_2012Metric
U101: 74HC373; SOIC-20W_7.5x12.8mm_P1.27mm
U102: ULN2803A; DIP-18_W7.62mm_Socket

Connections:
+5V: C101.1, C104.1, U101.20 (VCC); also elsewhere on the board
+12V: C102.1, C103.1, K101.1, K102.1, K103.1, K104.1, K105.1, K106.1, K107.1, K108.1, U102.10 (COM); also elsewhere on the board
/COMM0: J101.16, K101.13
/COMM1: J101.13, K102.13
/COMM2: J101.12, K103.13
/COMM3: J101.10, K104.13
/COMM4: J101.7, K108.13
/COMM5: J101.5, K107.13
/COMM6: J101.4, K106.13
/COMM7: J101.2, K105.13
/D0: U101.3 (D0); also elsewhere on the board
/D1: U101.4 (D1); also elsewhere on the board
/D2: U101.7 (D2); also elsewhere on the board
/D3: U101.8 (D3); also elsewhere on the board
/D4: U101.13 (D4); also elsewhere on the board
/D5: U101.14 (D5); also elsewhere on the board
/D6: U101.17 (D6); also elsewhere on the board
/D7: U101.18 (D7); also elsewhere on the board
/LATCH: U101.11 (LE); also elsewhere on the board
/OUT0: R107.2, U101.2 (O0), U102.1 (I1)
/OUT1: R108.2, U101.5 (O1), U102.2 (I2)
/OUT2: R105.2, U101.6 (O2), U102.3 (I3)
/OUT3: R106.2, U101.9 (O3), U102.4 (I4)
/OUT4: R103.2, U101.12 (O4), U102.5 (I5)
/OUT5: R104.2, U101.15 (O5), U102.6 (I6)
/OUT6: R101.2, U101.16 (O6), U102.7 (I7)
/OUT7: R102.2, U101.19 (O7), U102.8 (I8)
/RELAY0: D106.2 (A), K101.16, U102.11 (O8)
/RELAY1: D105.2 (A), K102.16, U102.12 (O7)
/RELAY2: D107.2 (A), K103.16, U102.13 (O6)
/RELAY3: D108.2 (A), K104.16, U102.14 (O5)
/RELAY4: D111.2 (A), K107.16, U102.15 (O4)
/RELAY5: D110.2 (A), K106.16, U102.16 (O3)
/RELAY6: D112.2 (A), K108.16, U102.17 (O2)
/RELAY7: D109.2 (A), K105.16, U102.18 (O1)
/SW0: J101.15, K101.9
/SW1: J101.14, K102.9
/SW2: J101.11, K103.9
/SW3: J101.9, K104.9
/SW4: J101.8, K108.9
/SW5: J101.6, K107.9
/SW6: J101.3, K106.9
/SW7: J101.1, K105.9
GND: C101.2, C102.2, C103.2, C104.2, D101.3 (K1), D101.4 (K2), D102.3 (K1), D102.4 (K2), D103.3 (K1), D103.4 (K2), D104.3 (K1), D104.4 (K2), D105.1 (K), D106.1 (K), D107.1 (K), D108.1 (K), D109.1 (K), D110.1 (K), D111.1 (K), D112.1 (K), U101.1 (OE), U101.10 (GND), U102.9 (GND); also elsewhere on the board
unnamed: D101.1 (A1), R101.1
unnamed: D101.2 (A2), R102.1
unnamed: D102.1 (A1), R103.1
unnamed: D102.2 (A2), R104.1
unnamed: D103.1 (A1), R105.1
unnamed: D103.2 (A2), R106.1
unnamed: D104.1 (A1), R107.1
unnamed: D104.2 (A2), R108.1

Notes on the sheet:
Place near relays

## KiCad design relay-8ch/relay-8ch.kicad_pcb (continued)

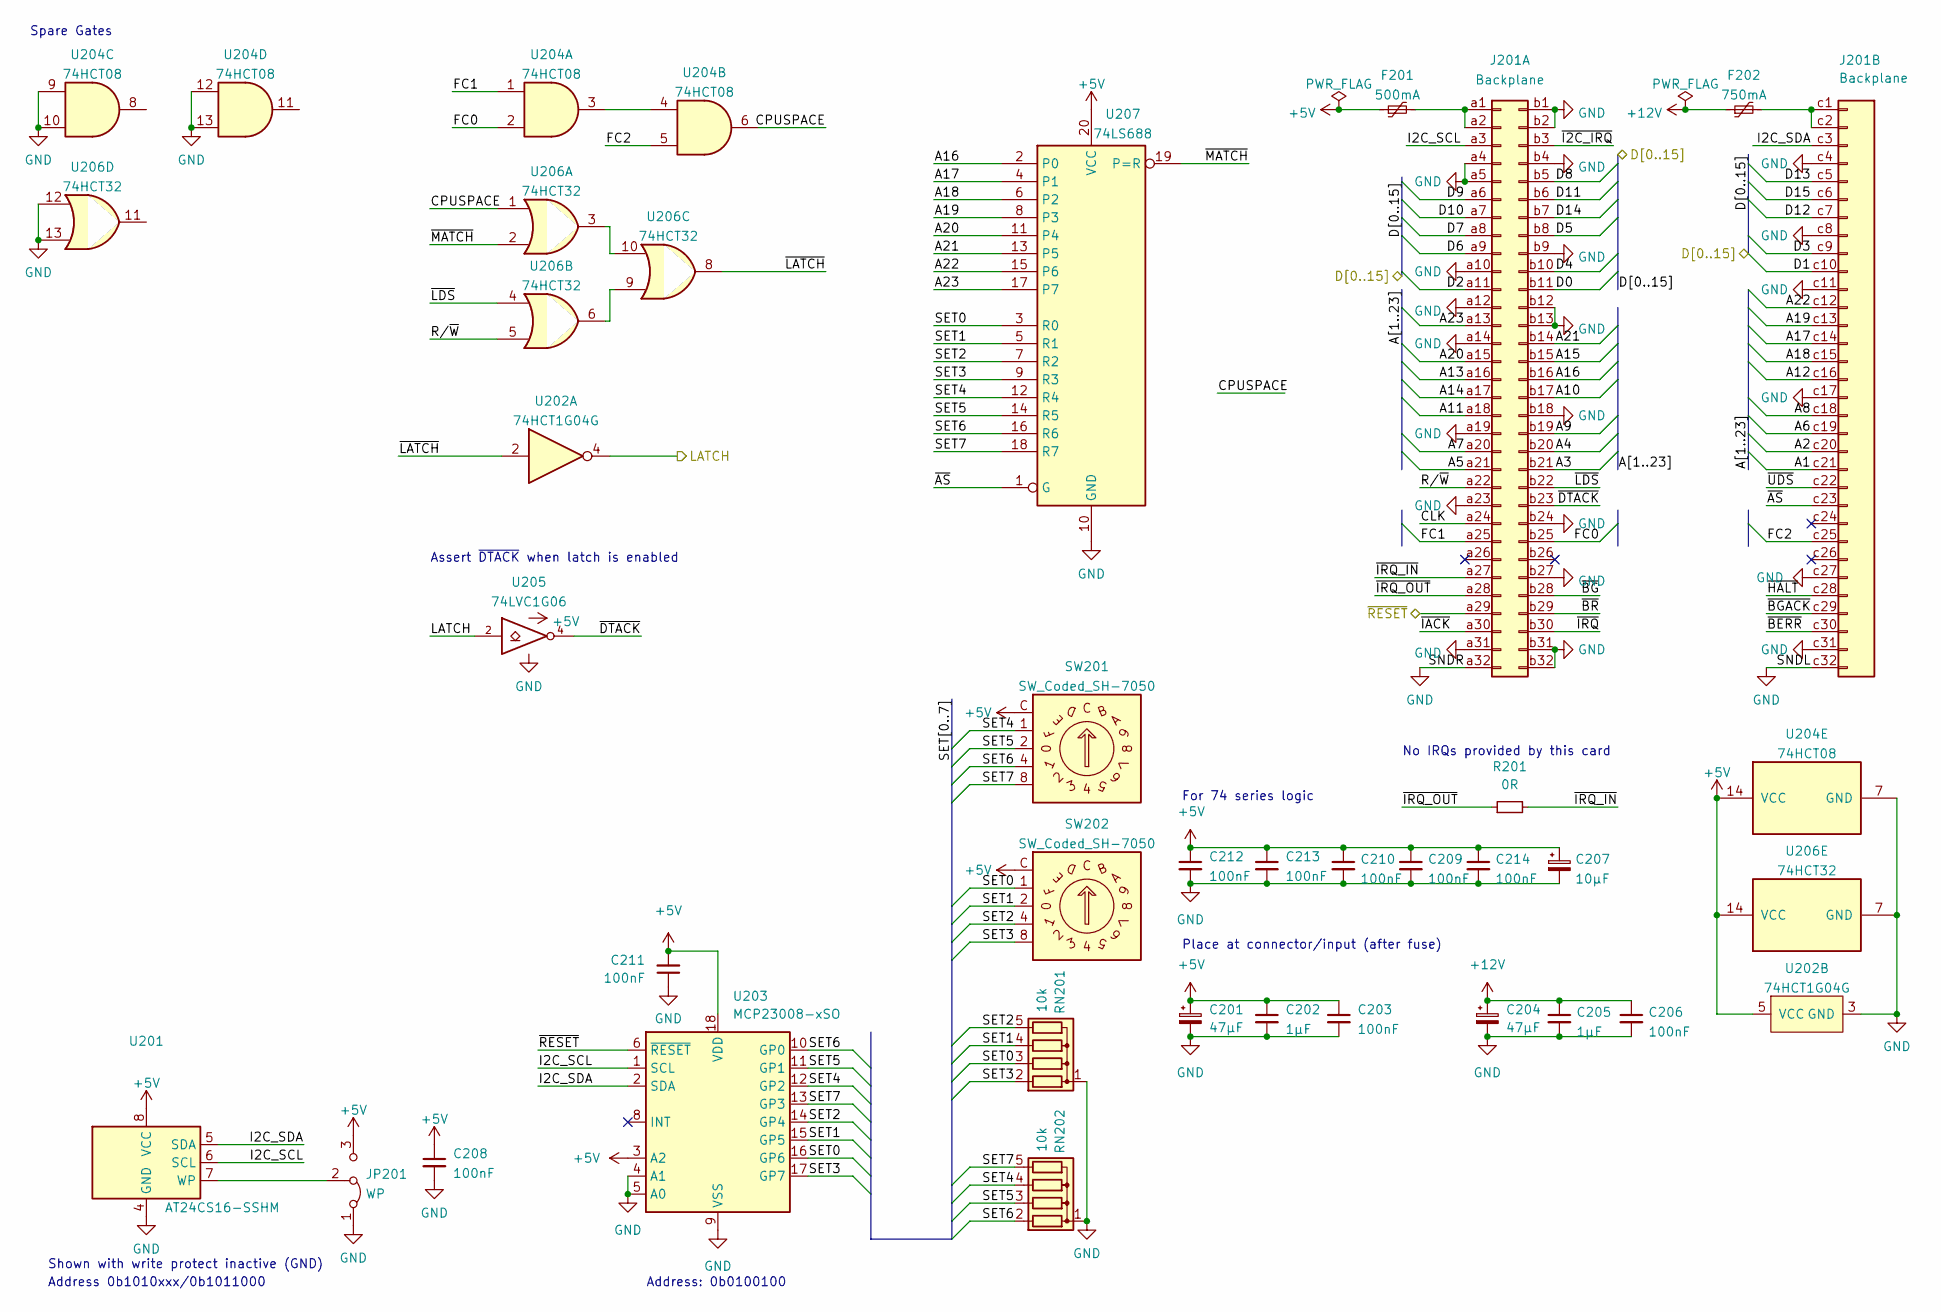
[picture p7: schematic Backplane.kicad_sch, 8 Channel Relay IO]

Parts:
C201, C204: 47µF; CP_Elec_6.3x5.7; MPN A768EB476M1ELAS042
C202, C205: 1µF; C_0805_2012Metric
C203, C206, C208, C209, C210, C211, C212, C213, C214: 100nF; C_0805_2012Metric
C207: 10µF; CP_EIA-3216-18_Kemet-A; MPN TAJA106K016RNJV
F201: 500mA; Fuse_1812_4532Metric; MPN 0ZCG0050FF2C
F202: 750mA; Fuse_1812_4532Metric; MPN 0ZCG0075FF2C
J201: Backplane; DIN41612_R_3x32_Male_Horizontal_THT
JP201: WP; SolderJumper-3_P1.3mm_Bridged2Bar12_Pad1.0x1.5mm
R201: 0R; R_0805_2012Metric; MPN RC0805JR-100RL
RN201, RN202: 10k; R_Array_SIP5; MPN 4605X-101-103LF
SW201, SW202: SW_Coded_SH-7050; Nidec_Copal_SH-7010C; MPN SH-7050MC
U201: AT24CS16-SSHM; SOIC-8_3.9x4.9mm_P1.27mm; MPN AT24CS32-SSHM-T
U202: 74HCT1G04G; SC-74-5_1.5x2.9mm_P0.95mm
U203: MCP23008-xSO; SOIC-18W_7.5x11.6mm_P1.27mm
U204: 74HCT08; SO-14_3.9x8.65mm_P1.27mm
U205: 74LVC1G06; SC-74-5_1.5x2.9mm_P0.95mm; MPN 74LVC1G06GV,125
U206: 74HCT32; SO-14_3.9x8.65mm_P1.27mm
U207: 74LS688; SOIC-20W_7.5x12.8mm_P1.27mm; MPN SN74LS688DWR

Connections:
+5V: C201.1, C202.1, C203.1, C207.1, C208.1, C209.1, C210.1, C211.2, C212.1, C213.1, C214.1, F201.1, JP201.3 (B), SW201.C, SW202.C, U201.8 (VCC), U202.5 (VCC), U203.3 (A2), U203.18 (VDD), U204.14 (VCC), U205.5 (VCC), U206.14 (VCC), U207.20 (VCC); also elsewhere on the board
+12V: C204.1, C205.1, C206.1, F202.1; also elsewhere on the board
/Backplane Connection/A1: J201.c21
/Backplane Connection/A2: J201.c20
/Backplane Connection/A3: J201.b21
/Backplane Connection/A4: J201.b20
/Backplane Connection/A5: J201.a21
/Backplane Connection/A6: J201.c19
/Backplane Connection/A7: J201.a20
/Backplane Connection/A8: J201.c18
/Backplane Connection/A9: J201.b19
/Backplane Connection/A10: J201.b17
/Backplane Connection/A11: J201.a18
/Backplane Connection/A12: J201.c16
/Backplane Connection/A13: J201.a16
/Backplane Connection/A14: J201.a17
/Backplane Connection/A15: J201.b15
/Backplane Connection/A16: J201.b16, U207.2 (P0)
/Backplane Connection/A17: J201.c14, U207.4 (P1)
/Backplane Connection/A18: J201.c15, U207.6 (P2)
/Backplane Connection/A19: J201.c13, U207.8 (P3)
/Backplane Connection/A20: J201.a15, U207.11 (P4)
/Backplane Connection/A21: J201.b14, U207.13 (P5)
/Backplane Connection/A22: J201.c12, U207.15 (P6)
/Backplane Connection/A23: J201.a13, U207.17 (P7)
/Backplane Connection/CLK: J201.a24
/Backplane Connection/CPUSPACE: U204.6, U206.1
/Backplane Connection/D8: J201.b5
/Backplane Connection/D9: J201.a6
/Backplane Connection/D10: J201.a7
/Backplane Connection/D11: J201.b6
/Backplane Connection/D12: J201.c7
/Backplane Connection/D13: J201.c5
/Backplane Connection/D14: J201.b7
/Backplane Connection/D15: J201.c6
/Backplane Connection/FC0: J201.b25, U204.2
/Backplane Connection/FC1: J201.a25, U204.1
/Backplane Connection/FC2: J201.c25, U204.5
/Backplane Connection/I2C_SCL: J201.a3, U201.6 (SCL), U203.1 (SCL)
/Backplane Connection/I2C_SDA: J201.c3, U201.5 (SDA), U203.2 (SDA)
/Backplane Connection/R/~W: J201.a22, U206.5
/Backplane Connection/SET0: RN201.3 (R2), SW202.1, U203.16 (GP6), U207.3 (R0)
/Backplane Connection/SET1: RN201.4 (R3), SW202.2, U203.15 (GP5), U207.5 (R1)
/Backplane Connection/SET2: RN201.5 (R4), SW202.4, U203.14 (GP4), U207.7 (R2)
/Backplane Connection/SET3: RN201.2 (R1), SW202.8, U203.17 (GP7), U207.9 (R3)
/Backplane Connection/SET4: RN202.4 (R3), SW201.1, U203.12 (GP2), U207.12 (R4)
/Backplane Connection/SET5: RN202.3 (R2), SW201.2, U203.11 (GP1), U207.14 (R5)
/Backplane Connection/SET6: RN202.2 (R1), SW201.4, U203.10 (GP0), U207.16 (R6)
/Backplane Connection/SET7: RN202.5 (R4), SW201.8, U203.13 (GP3), U207.18 (R7)
/Backplane Connection/~AS: J201.c23, U207.1 (G)
/Backplane Connection/~BERR: J201.c30
/Backplane Connection/~BGACK: J201.c29
/Backplane Connection/~BG: J201.b28
/Backplane Connection/~BR: J201.b29
/Backplane Connection/~DTACK: J201.b23, U205.4
/Backplane Connection/~HALT: J201.c28
/Backplane Connection/~I2C_IRQ: J201.b3
/Backplane Connection/~IACK: J201.a30
/Backplane Connection/~IRQ_IN: J201.a27, R201.2
/Backplane Connection/~IRQ_OUT: J201.a28, R201.1
/Backplane Connection/~IRQ: J201.b30
/Backplane Connection/~LATCH: U202.2, U206.8
/Backplane Connection/~LDS: J201.b22, U206.4
/Backplane Connection/~MATCH: U206.2, U207.19 (P=R)
/Backplane Connection/~RESET: J201.a29, U203.6 (~RESET)
/Backplane Connection/~UDS: J201.c22
/D0: J201.b11; also elsewhere on the board
/D1: J201.c10; also elsewhere on the board
/D2: J201.a11; also elsewhere on the board
/D3: J201.c9; also elsewhere on the board
/D4: J201.b10; also elsewhere on the board
/D5: J201.b8; also elsewhere on the board
/D6: J201.a9; also elsewhere on the board
/D7: J201.a8; also elsewhere on the board
/LATCH: U202.4, U205.2; also elsewhere on the board
GND: C201.2, C202.2, C203.2, C204.2, C205.2, C206.2, C207.2, C208.2, C209.2, C210.2, C211.1, C212.2, C213.2, C214.2, J201.a4, J201.a5, J201.a10, J201.a12, J201.a14, J201.a19, J201.a23, J201.a31, J201.a32, J201.b1, J201.b2, J201.b4, J201.b9, J201.b12, J201.b13, J201.b18, J201.b24, J201.b27, J201.b31, J201.b32, J201.c4, J201.c8, J201.c11, J201.c17, J201.c27, J201.c31, J201.c32, JP201.1 (A), RN201.1 (common), RN202.1 (common), U201.4 (GND), U202.3 (GND), U203.4 (A1), U203.5 (A0), U203.9 (VSS), U204.7 (GND), U204.9, U204.10, U204.12, U204.13, U205.3 (GND), U206.7 (GND), U206.12, U206.13, U207.10 (GND); also elsewhere on the board
unnamed: F201.2, J201.a1, J201.a2
unnamed: F202.2, J201.c1, J201.c2
unnamed: JP201.2 (C), U201.7 (WP)
unnamed: U204.3, U204.4
unnamed: U206.6, U206.9
unnamed: U206.3, U206.10

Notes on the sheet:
Shown with write protect inactive (GND)
Place at connector/input (after fuse)
No IRQs provided by this card
Spare Gates
Assert ~{DTACK} when latch is enabled
For 74 series logic
Address 0b1010xxx/0b1011000
Address: 0b0100100

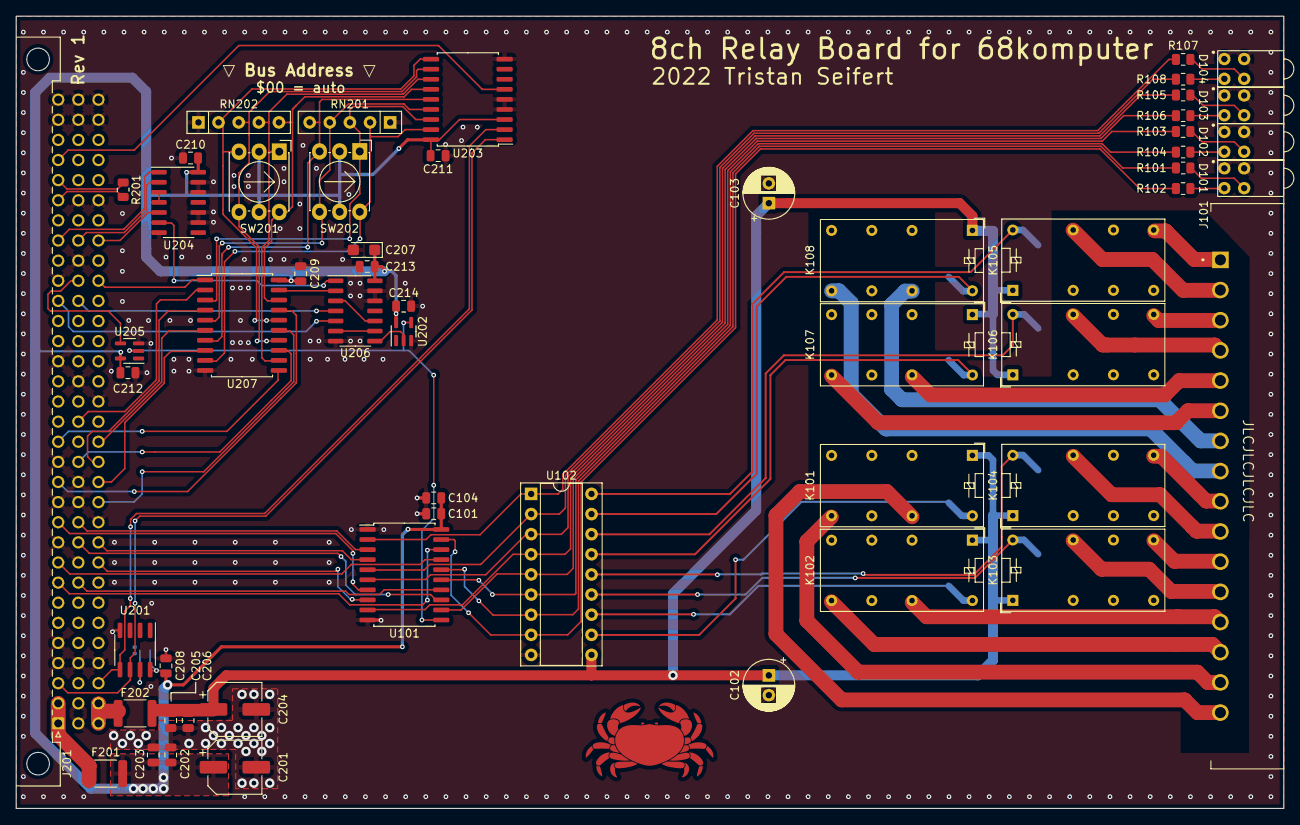
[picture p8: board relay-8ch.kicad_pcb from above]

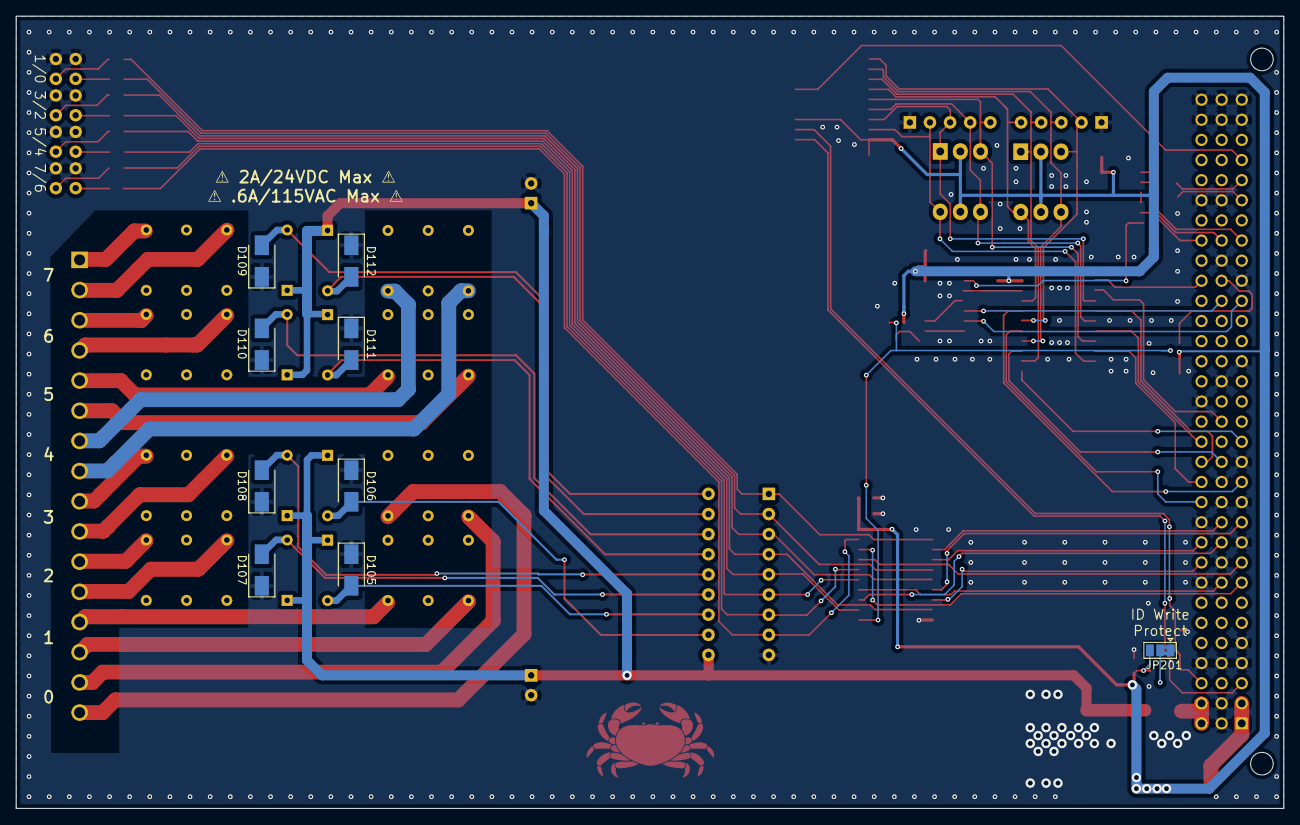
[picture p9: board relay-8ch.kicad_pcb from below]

Board: 2 copper layers, 160.0 x 100.0 mm, 65 parts (9 on the bottom side), 89 nets.

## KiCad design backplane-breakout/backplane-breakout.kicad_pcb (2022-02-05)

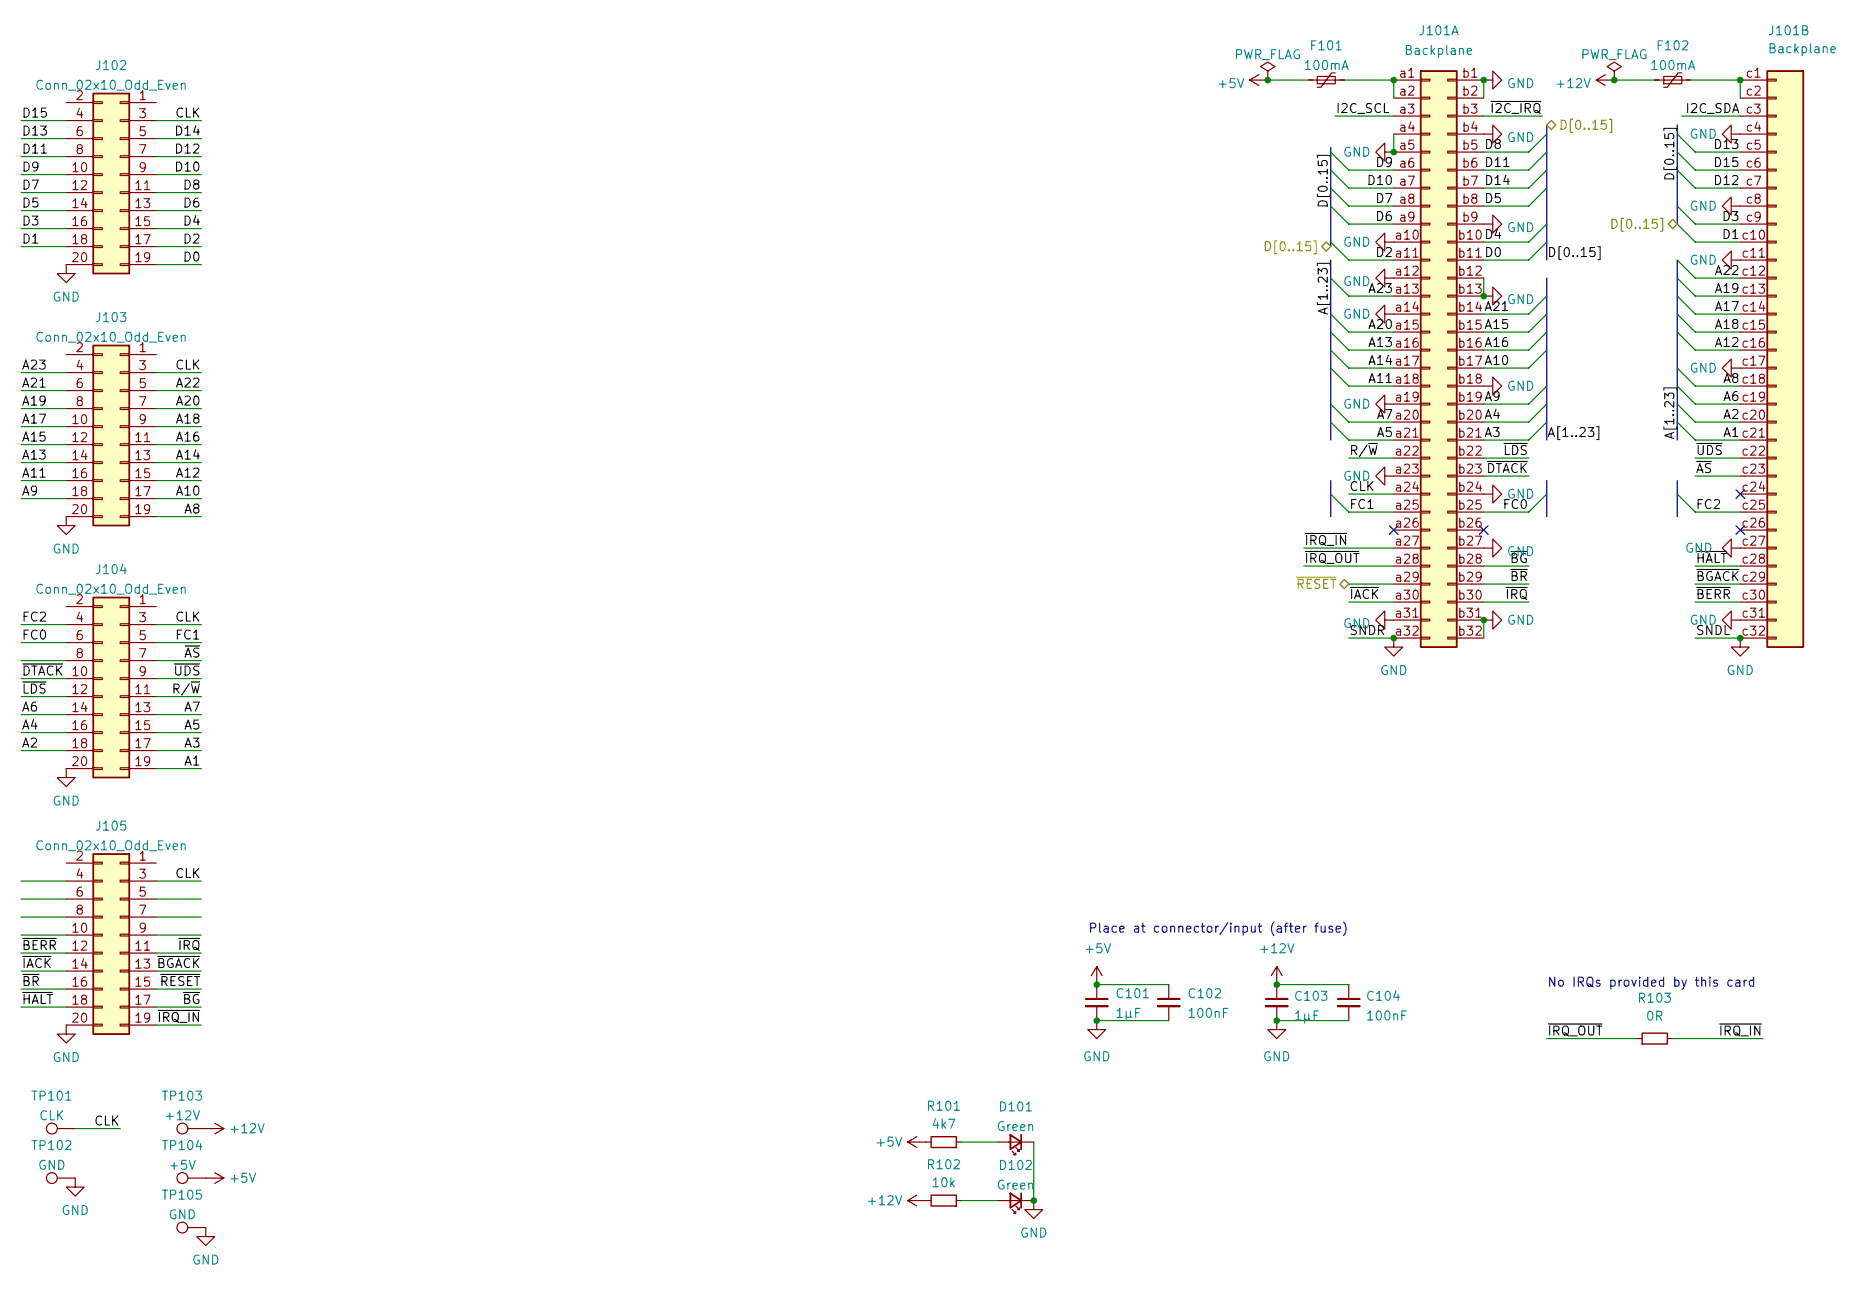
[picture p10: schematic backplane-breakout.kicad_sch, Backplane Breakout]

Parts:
C101, C103: 1µF; C_0805_2012Metric
C102, C104: 100nF; C_0805_2012Metric
D101, D102: Green; LED_0805_2012Metric
F101, F102: 100mA; Fuse_1812_4532Metric; MPN PTS181230V010
J101: Backplane; DIN41612_R_3x32_Male_Horizontal_THT; MPN 86093967113H55ELF
J102, J103, J104, J105: Conn_02x10_Odd_Even; Shrouded_PinHeader_2x10_P2.54mm_Vertical
R101: 4k7; R_0805_2012Metric
R102: 10k; R_0805_2012Metric
R103: 0R; R_0805_2012Metric; MPN RC0805JR-100RL
TP101: CLK; TestPoint_Keystone_5000-5004_Miniature
TP102, TP105: GND; TestPoint_Keystone_5000-5004_Miniature
TP103: +12V; TestPoint_Keystone_5000-5004_Miniature
TP104: +5V; TestPoint_Keystone_5000-5004_Miniature

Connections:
+5V: C101.1, C102.1, F101.1, R101.2, TP104.1
+12V: C103.1, C104.1, F102.1, R102.2, TP103.1
/A1: J101.c21, J104.19
/A2: J101.c20, J104.18
/A3: J101.b21, J104.17
/A4: J101.b20, J104.16
/A5: J101.a21, J104.15
/A6: J101.c19, J104.14
/A7: J101.a20, J104.13
/A8: J101.c18, J103.19
/A9: J101.b19, J103.18
/A10: J101.b17, J103.17
/A11: J101.a18, J103.16
/A12: J101.c16, J103.15
/A13: J101.a16, J103.14
/A14: J101.a17, J103.13
/A15: J101.b15, J103.12
/A16: J101.b16, J103.11
/A17: J101.c14, J103.10
/A18: J101.c15, J103.9
/A19: J101.c13, J103.8
/A20: J101.a15, J103.7
/A21: J101.b14, J103.6
/A22: J101.c12, J103.5
/A23: J101.a13, J103.4
/CLK: J101.a24, J102.3, J103.3, J104.3, J105.3, TP101.1
/D0: J101.b11, J102.19
/D1: J101.c10, J102.18
/D2: J101.a11, J102.17
/D3: J101.c9, J102.16
/D4: J101.b10, J102.15
/D5: J101.b8, J102.14
/D6: J101.a9, J102.13
/D7: J101.a8, J102.12
/D8: J101.b5, J102.11
/D9: J101.a6, J102.10
/D10: J101.a7, J102.9
/D11: J101.b6, J102.8
/D12: J101.c7, J102.7
/D13: J101.c5, J102.6
/D14: J101.b7, J102.5
/D15: J101.c6, J102.4
/FC0: J101.b25, J104.6
/FC1: J101.a25, J104.5
/FC2: J101.c25, J104.4
/I2C_SCL: J101.a3
/I2C_SDA: J101.c3
/R/~W: J101.a22, J104.11
/~AS: J101.c23, J104.7
/~BERR: J101.c30, J105.12
/~BGACK: J101.c29, J105.13
/~BG: J101.b28, J105.17
/~BR: J101.b29, J105.16
/~DTACK: J101.b23, J104.10
/~HALT: J101.c28, J105.18
/~I2C_IRQ: J101.b3
/~IACK: J101.a30, J105.14
/~IRQ_IN: J101.a27, J105.19, R103.2
/~IRQ_OUT: J101.a28, R103.1
/~IRQ: J101.b30, J105.11
/~LDS: J101.b22, J104.12
/~RESET: J101.a29, J105.15
/~UDS: J101.c22, J104.9
GND: C101.2, C102.2, C103.2, C104.2, D101.1 (K), D102.1 (K), J101.a4, J101.a5, J101.a10, J101.a12, J101.a14, J101.a19, J101.a23, J101.a31, J101.a32, J101.b1, J101.b2, J101.b4, J101.b9, J101.b12, J101.b13, J101.b18, J101.b24, J101.b27, J101.b31, J101.b32, J101.c4, J101.c8, J101.c11, J101.c17, J101.c27, J101.c31, J101.c32, J102.20, J103.20, J104.20, J105.20, TP102.1, TP105.1
unnamed: D101.2 (A), R101.1
unnamed: D102.2 (A), R102.1
unnamed: F101.2, J101.a1, J101.a2
unnamed: F102.2, J101.c1, J101.c2

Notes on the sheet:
No IRQs provided by this card
Place at connector/input (after fuse)

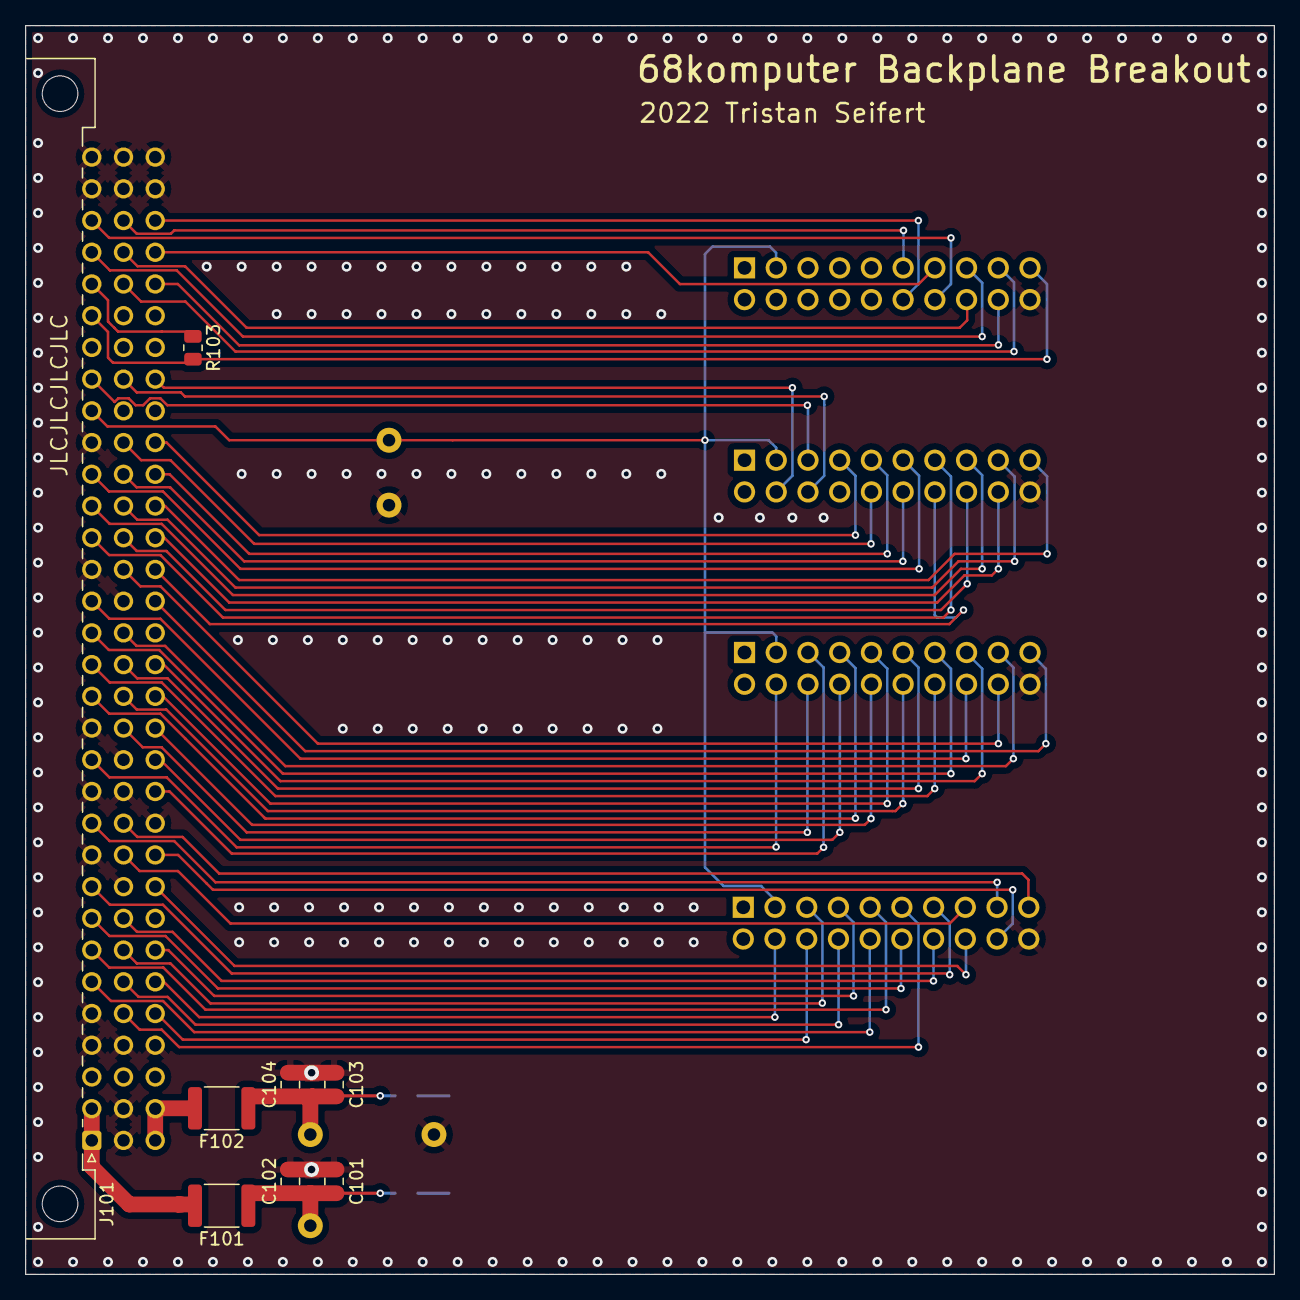
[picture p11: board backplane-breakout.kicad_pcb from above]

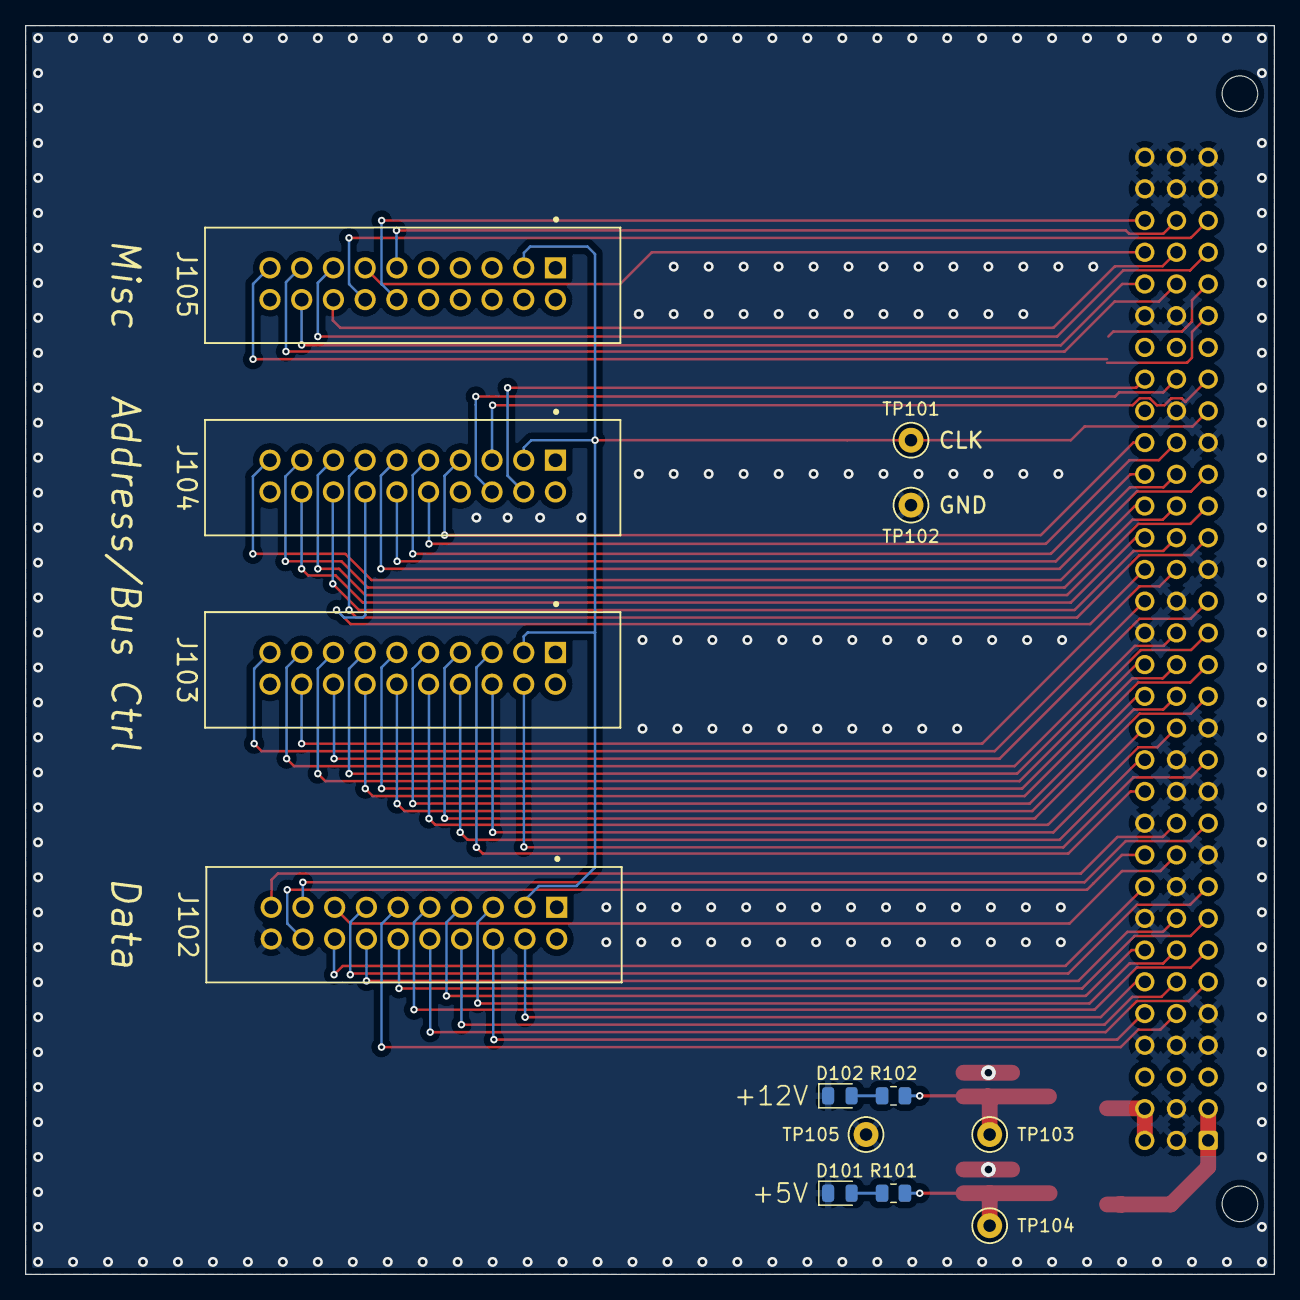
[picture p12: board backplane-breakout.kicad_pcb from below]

Board: 2 copper layers, 100.0 x 100.0 mm, 21 parts (13 on the bottom side), 65 nets.

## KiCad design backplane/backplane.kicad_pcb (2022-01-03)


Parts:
C101, C102, C103: 100nF; C_0805_2012Metric
C104: 10µF; CP_EIA-3216-18_Kemet-A; MPN TAJA106K016RNJV
D101, D102: Green; LED_0805_2012Metric
JP101: WP; SolderJumper-3_P1.3mm_Bridged2Bar12_Pad1.0x1.5mm
R101, R103, R104, R105, R106: 4k7; R_0805_2012Metric
R102: 10k; R_0805_2012Metric
U101: MCP23008-xSO; SOIC-18W_7.5x11.6mm_P1.27mm
U102: PCA9548ADB; SSOP-24_5.3x8.2mm_P0.65mm
U103: AT24CS32-SSHM; SOIC-8_3.9x4.9mm_P1.27mm; MPN AT24CS32-SSHM-T

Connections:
+5V: C101.2, C102.2, C103.1, C104.1, JP101.3 (B), R101.2, R103.1, R104.1, R105.1, R106.1, U101.4 (A1), U101.18 (VDD), U102.24 (VCC), U103.1 (A0), U103.2 (A1), U103.3 (A2), U103.8 (VCC); also elsewhere on the board
+12V: R102.2; also elsewhere on the board
/BPL_SCL: R103.2, U101.1 (SCL), U102.20 (SC7), U103.6 (SCL)
/BPL_SDA: R104.2, U101.2 (SDA), U102.19 (SD7), U103.5 (SDA)
/I2C_SCL: U102.22 (SCL); also elsewhere on the board
/I2C_SDA: U102.23 (SDA); also elsewhere on the board
/MGMT_SCL: R105.2, U102.18 (SC6); also elsewhere on the board
/MGMT_SDA: R106.2, U102.17 (SD6); also elsewhere on the board
/~BPL_IRQ: U101.8 (INT)
/~DETECT0: U101.12 (GP2); also elsewhere on the board
/~DETECT1: U101.13 (GP3); also elsewhere on the board
/~DETECT2: U101.14 (GP4); also elsewhere on the board
/~DETECT3: U101.15 (GP5); also elsewhere on the board
/~DETECT4: U101.16 (GP6); also elsewhere on the board
/~DETECT5: U101.17 (GP7); also elsewhere on the board
/~RESET: U101.6 (~RESET), U102.3 (~RESET); also elsewhere on the board
GND: C101.1, C102.1, C103.2, C104.2, D101.1 (K), D102.1 (K), JP101.1 (A), U101.3 (A2), U101.5 (A0), U101.9 (VSS), U102.1 (A0), U102.2 (A1), U102.12 (GND), U102.21 (A2), U103.4 (GND); also elsewhere on the board
unnamed: D101.2 (A), R101.1
unnamed: D102.2 (A), R102.1
unnamed: JP101.2 (C), U103.7 (WP)

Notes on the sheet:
Address: 0b1110000
Address: 0b0100010
Place near I2C stuff
Shown with write protect inactive (GND)


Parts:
C201: 100µF; CP_Radial_D8.0mm_P3.50mm; MPN A750KK107M1EAAE040
C202, C205: 1µF; C_0805_2012Metric
C203, C206: 100nF; C_0805_2012Metric
C204: 100µF; CP_Radial_D5.0mm_P2.00mm; MPN A750BK107M1AAAE024
J201: Management; DIN41612_C2_3x16_Female_Vertical_THT

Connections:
+5V: C204.1, C205.1, C206.1, J201.a1, J201.a2, J201.a3, J201.b1, J201.b2, J201.b3, J201.c1, J201.c2, J201.c3; also elsewhere on the board
+12V: C201.1, C202.1, C203.1, J201.a5, J201.b5, J201.c5; also elsewhere on the board
/MGMT_SCL: J201.a14; also elsewhere on the board
/MGMT_SDA: J201.c14; also elsewhere on the board
/Management Controller/SNDL: J201.c16
/Management Controller/SNDR: J201.a16
/Management Controller/~IRQ: J201.c13
/~EXTRST: J201.a12; also elsewhere on the board
GND: C201.2, C202.2, C203.2, C204.2, C205.2, C206.2, J201.a4, J201.a6, J201.b4, J201.b6, J201.b7, J201.b8, J201.b9, J201.b10, J201.b11, J201.b12, J201.b13, J201.b14, J201.b15, J201.b16, J201.c4, J201.c6; also elsewhere on the board

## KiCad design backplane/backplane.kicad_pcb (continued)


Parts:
C301: 10µF; CP_EIA-3216-18_Kemet-A
C302: 100nF; C_0805_2012Metric
J301: CPU; DIN41612_C_3x32_Female_Vertical_THT

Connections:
+5V: C301.1, C302.1, J301.a1, J301.a2; also elsewhere on the board
+12V: J301.c1, J301.c2; also elsewhere on the board
/A1: J301.c21; also elsewhere on the board
/A2: J301.c20; also elsewhere on the board
/A3: J301.b21; also elsewhere on the board
/A4: J301.b20; also elsewhere on the board
/A5: J301.a21; also elsewhere on the board
/A6: J301.c19; also elsewhere on the board
/A7: J301.a20; also elsewhere on the board
/A8: J301.c18; also elsewhere on the board
/A9: J301.b19; also elsewhere on the board
/A10: J301.b17; also elsewhere on the board
/A11: J301.a18; also elsewhere on the board
/A12: J301.c16; also elsewhere on the board
/A13: J301.a16; also elsewhere on the board
/A14: J301.a17; also elsewhere on the board
/A15: J301.b15; also elsewhere on the board
/A16: J301.b16; also elsewhere on the board
/A17: J301.c14; also elsewhere on the board
/A18: J301.c15; also elsewhere on the board
/A19: J301.c13; also elsewhere on the board
/A20: J301.a15; also elsewhere on the board
/A21: J301.b14; also elsewhere on the board
/A22: J301.c12; also elsewhere on the board
/A23: J301.a13; also elsewhere on the board
/CPU Board/CLK: J301.a24
/CPU Board/SNDL: J301.c32
/CPU Board/SNDR: J301.a32
/D0: J301.b11; also elsewhere on the board
/D1: J301.c10; also elsewhere on the board
/D2: J301.a11; also elsewhere on the board
/D3: J301.c9; also elsewhere on the board
/D4: J301.b10; also elsewhere on the board
/D5: J301.b8; also elsewhere on the board
/D6: J301.a9; also elsewhere on the board
/D7: J301.a8; also elsewhere on the board
/D8: J301.b5; also elsewhere on the board
/D9: J301.a6; also elsewhere on the board
/D10: J301.a7; also elsewhere on the board
/D11: J301.b6; also elsewhere on the board
/D12: J301.c7; also elsewhere on the board
/D13: J301.c5; also elsewhere on the board
/D14: J301.b7; also elsewhere on the board
/D15: J301.c6; also elsewhere on the board
/FC0: J301.b25; also elsewhere on the board
/FC1: J301.a25; also elsewhere on the board
/FC2: J301.c25; also elsewhere on the board
/I2C_SCL: J301.a3; also elsewhere on the board
/I2C_SDA: J301.c3; also elsewhere on the board
/R/~W: J301.a22; also elsewhere on the board
/~AS: J301.c23; also elsewhere on the board
/~BERR: J301.c30; also elsewhere on the board
/~BGACK: J301.c29; also elsewhere on the board
/~BG: J301.b28; also elsewhere on the board
/~BR: J301.b29; also elsewhere on the board
/~DTACK: J301.b23; also elsewhere on the board
/~EXTRST: J301.c27; also elsewhere on the board
/~EXT: J301.a28; also elsewhere on the board
/~HALT: J301.c28; also elsewhere on the board
/~I2C_IRQ: J301.b3
/~IACK: J301.a30; also elsewhere on the board
/~IRQ: J301.b30; also elsewhere on the board
/~LDS: J301.b22; also elsewhere on the board
/~RESET: J301.a29; also elsewhere on the board
/~UDS: J301.c22; also elsewhere on the board
GND: C301.2, C302.2, J301.a4, J301.a5, J301.a10, J301.a12, J301.a14, J301.a19, J301.a23, J301.a31, J301.b1, J301.b2, J301.b4, J301.b9, J301.b12, J301.b13, J301.b18, J301.b24, J301.b31, J301.b32, J301.c4, J301.c8, J301.c11, J301.c17, J301.c31; also elsewhere on the board


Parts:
C401, C406, C409, C410: 10µF; CP_EIA-3216-18_Kemet-A; MPN TAJA106K016RNJV
C402, C403, C404, C405, C407, C408, C411: 100nF; C_0805_2012Metric
RN401: 10k; R_Array_SIP5; MPN 4605X-101-103LF
U401, U402, U403, U404, U405, U406: 74HC245; TSSOP-20_4.4x6.5mm_P0.65mm; MPN 74HC245PW,118
U407: ATF22V10C; DIP-24_W7.62mm_Socket

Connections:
+5V: C401.1, C402.1, C403.1, C404.1, C405.1, C406.1, C407.1, C408.1, C409.1, C410.1, C411.1, U401.20 (VCC), U402.20 (VCC), U403.20 (VCC), U404.20 (VCC), U405.20 (VCC), U406.20 (VCC), U407.24 (VCC); also elsewhere on the board
/A1: U405.5 (A3); also elsewhere on the board
/A2: U405.8 (A6); also elsewhere on the board
/A3: U405.4 (A2); also elsewhere on the board
/A4: U405.7 (A5); also elsewhere on the board
/A5: U405.3 (A1); also elsewhere on the board
/A6: U404.2 (A0); also elsewhere on the board
/A7: U405.6 (A4); also elsewhere on the board
/A8: U404.4 (A2); also elsewhere on the board
/A9: U405.9 (A7); also elsewhere on the board
/A10: U404.6 (A4); also elsewhere on the board
/A11: U404.3 (A1); also elsewhere on the board
/A12: U404.9 (A7); also elsewhere on the board
/A13: U404.7 (A5); also elsewhere on the board
/A14: U404.5 (A3); also elsewhere on the board
/A15: U403.3 (A1); also elsewhere on the board
/A16: U404.8 (A6); also elsewhere on the board
/A17: U403.6 (A4); also elsewhere on the board
/A18: U403.4 (A2); also elsewhere on the board
/A19: U403.8 (A6); also elsewhere on the board
/A20: U403.2 (A0); also elsewhere on the board
/A21: U403.5 (A3); also elsewhere on the board
/A22: U403.9 (A7); also elsewhere on the board
/A23: U403.7 (A5); also elsewhere on the board
/D0: U402.3 (A1); also elsewhere on the board
/D1: U402.5 (A3); also elsewhere on the board
/D2: U402.2 (A0); also elsewhere on the board
/D3: U402.6 (A4); also elsewhere on the board
/D4: U402.4 (A2); also elsewhere on the board
/D5: U402.8 (A6); also elsewhere on the board
/D6: U402.7 (A5); also elsewhere on the board
/D7: U402.9 (A7); also elsewhere on the board
/D8: U401.8 (A6); also elsewhere on the board
/D9: U401.5 (A3); also elsewhere on the board
/D10: U401.2 (A0); also elsewhere on the board
/D11: U401.6 (A4); also elsewhere on the board
/D12: U401.4 (A2); also elsewhere on the board
/D13: U401.9 (A7); also elsewhere on the board
/D14: U401.3 (A1); also elsewhere on the board
/D15: U401.7 (A5); also elsewhere on the board
/Expansion Slots/ADDR_DIR: U403.1 (A->B), U404.1 (A->B), U405.1 (A->B), U406.1 (A->B), U407.17 (IO4)
/Expansion Slots/DATA_DIR: U401.1 (A->B), U402.1 (A->B), U407.14 (IO1)
/Expansion Slots/EA1: U405.15 (B3); also elsewhere on the board
/Expansion Slots/EA2: U405.12 (B6); also elsewhere on the board
/Expansion Slots/EA3: U405.16 (B2); also elsewhere on the board
/Expansion Slots/EA4: U405.13 (B5); also elsewhere on the board
/Expansion Slots/EA5: U405.17 (B1); also elsewhere on the board
/Expansion Slots/EA6: U404.18 (B0); also elsewhere on the board
/Expansion Slots/EA7: U405.14 (B4); also elsewhere on the board
/Expansion Slots/EA8: U404.16 (B2); also elsewhere on the board
/Expansion Slots/EA9: U405.11 (B7); also elsewhere on the board
/Expansion Slots/EA10: U404.14 (B4); also elsewhere on the board
/Expansion Slots/EA11: U404.17 (B1); also elsewhere on the board
/Expansion Slots/EA12: U404.11 (B7); also elsewhere on the board
/Expansion Slots/EA13: U404.13 (B5); also elsewhere on the board
/Expansion Slots/EA14: U404.15 (B3); also elsewhere on the board
/Expansion Slots/EA15: U403.17 (B1); also elsewhere on the board
/Expansion Slots/EA16: U404.12 (B6); also elsewhere on the board
/Expansion Slots/EA17: U403.14 (B4); also elsewhere on the board
/Expansion Slots/EA18: U403.16 (B2); also elsewhere on the board
/Expansion Slots/EA19: U403.12 (B6); also elsewhere on the board
/Expansion Slots/EA20: U403.18 (B0); also elsewhere on the board
/Expansion Slots/EA21: U403.15 (B3); also elsewhere on the board
/Expansion Slots/EA22: U403.11 (B7); also elsewhere on the board
/Expansion Slots/EA23: U403.13 (B5); also elsewhere on the board
/Expansion Slots/ED0: U402.17 (B1); also elsewhere on the board
/Expansion Slots/ED1: U402.15 (B3); also elsewhere on the board
/Expansion Slots/ED2: U402.18 (B0); also elsewhere on the board
/Expansion Slots/ED3: U402.14 (B4); also elsewhere on the board
/Expansion Slots/ED4: U402.16 (B2); also elsewhere on the board
/Expansion Slots/ED5: U402.12 (B6); also elsewhere on the board
/Expansion Slots/ED6: U402.13 (B5); also elsewhere on the board
/Expansion Slots/ED7: U402.11 (B7); also elsewhere on the board
/Expansion Slots/ED8: U401.12 (B6); also elsewhere on the board
/Expansion Slots/ED9: U401.15 (B3); also elsewhere on the board
/Expansion Slots/ED10: U401.18 (B0); also elsewhere on the board
/Expansion Slots/ED11: U401.14 (B4); also elsewhere on the board
/Expansion Slots/ED12: U401.16 (B2); also elsewhere on the board
/Expansion Slots/ED13: U401.11 (B7); also elsewhere on the board
/Expansion Slots/ED14: U401.17 (B1); also elsewhere on the board
/Expansion Slots/ED15: U401.13 (B5); also elsewhere on the board
/Expansion Slots/EFC0: RN401.3 (R2), U406.17 (B1); also elsewhere on the board
/Expansion Slots/EFC1: RN401.4 (R3), U406.18 (B0); also elsewhere on the board
/Expansion Slots/EFC2: RN401.2 (R1), U406.16 (B2); also elsewhere on the board
/Expansion Slots/ER/~W: U406.11 (B7); also elsewhere on the board
/Expansion Slots/~ADDR_OE: U403.19 (CE), U404.19 (CE), U405.19 (CE), U406.19 (CE), U407.16 (IO3)
/Expansion Slots/~DATA_OE: U401.19 (CE), U402.19 (CE), U407.15 (IO2)
/Expansion Slots/~EAS: U406.14 (B4); also elsewhere on the board
/Expansion Slots/~ELDS: U406.12 (B6); also elsewhere on the board
/Expansion Slots/~EUDS: U406.13 (B5); also elsewhere on the board
/FC0: U406.3 (A1); also elsewhere on the board
/FC1: U406.2 (A0); also elsewhere on the board
/FC2: U406.4 (A2); also elsewhere on the board
/R/~W: U406.9 (A7), U407.13 (IN12); also elsewhere on the board
/~AS: U406.6 (A4), U407.9 (IN9); also elsewhere on the board
/~BGACK: U407.5 (IN5); also elsewhere on the board
/~EXT: U407.6 (IN6); also elsewhere on the board
/~LDS: U406.8 (A6), U407.11 (IN11); also elsewhere on the board
/~UDS: U406.7 (A5), U407.10 (IN10); also elsewhere on the board
GND: C401.2, C402.2, C403.2, C404.2, C405.2, C406.2, C407.2, C408.2, C409.2, C410.2, C411.2, RN401.1 (common), U401.10 (GND), U402.10 (GND), U403.10 (GND), U404.10 (GND), U405.10 (GND), U406.10 (GND), U407.12 (GND); also elsewhere on the board

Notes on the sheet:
One per buffer
1x for D buffers, 2x for A buffers
For buffer direction GAL


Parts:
C501, C510: 47µF; CP_Elec_6.3x5.7; MPN A768EB476M1ELAS042
C502, C504, C506, C508: 10µF; CP_Radial_D4.0mm_P1.50mm; MPN ESY106M035AB2AA
C503, C505, C507, C509: 10µF; CP_EIA-3216-18_Kemet-A; MPN TAJA106K016RNJV
C511, C512, C513, C514, C515, C516, C517, C518: 100nF; C_0805_2012Metric
J501: Slot 1; DIN41612_C_3x32_Female_Vertical_THT
J502: Slot 4; DIN41612_C_3x32_Female_Vertical_THT
J503: Slot 2; DIN41612_C_3x32_Female_Vertical_THT
J504: Slot 3; DIN41612_C_3x32_Female_Vertical_THT; MPN 86093968124H55V1LF

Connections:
+5V: C501.1, C503.1, C505.1, C507.1, C509.1, C512.1, C514.1, C516.1, C518.1, J501.a1, J501.a2, J502.a1, J502.a2, J503.a1, J503.a2, J504.a1, J504.a2; also elsewhere on the board
+12V: C502.1, C504.1, C506.1, C508.1, C510.1, C511.1, C513.1, C515.1, C517.1, J501.c1, J501.c2, J502.c1, J502.c2, J503.c1, J503.c2, J504.c1, J504.c2; also elsewhere on the board
/Expansion Slots/EA1: J501.c21, J502.c21, J503.c21, J504.c21; also elsewhere on the board
/Expansion Slots/EA2: J501.c20, J502.c20, J503.c20, J504.c20; also elsewhere on the board
/Expansion Slots/EA3: J501.b21, J502.b21, J503.b21, J504.b21; also elsewhere on the board
/Expansion Slots/EA4: J501.b20, J502.b20, J503.b20, J504.b20; also elsewhere on the board
/Expansion Slots/EA5: J501.a21, J502.a21, J503.a21, J504.a21; also elsewhere on the board
/Expansion Slots/EA6: J501.c19, J502.c19, J503.c19, J504.c19; also elsewhere on the board
/Expansion Slots/EA7: J501.a20, J502.a20, J503.a20, J504.a20; also elsewhere on the board
/Expansion Slots/EA8: J501.c18, J502.c18, J503.c18, J504.c18; also elsewhere on the board
/Expansion Slots/EA9: J501.b19, J502.b19, J503.b19, J504.b19; also elsewhere on the board
/Expansion Slots/EA10: J501.b17, J502.b17, J503.b17, J504.b17; also elsewhere on the board
/Expansion Slots/EA11: J501.a18, J502.a18, J503.a18, J504.a18; also elsewhere on the board
/Expansion Slots/EA12: J501.c16, J502.c16, J503.c16, J504.c16; also elsewhere on the board
/Expansion Slots/EA13: J501.a16, J502.a16, J503.a16, J504.a16; also elsewhere on the board
/Expansion Slots/EA14: J501.a17, J502.a17, J503.a17, J504.a17; also elsewhere on the board
/Expansion Slots/EA15: J501.b15, J502.b15, J503.b15, J504.b15; also elsewhere on the board
/Expansion Slots/EA16: J501.b16, J502.b16, J503.b16, J504.b16; also elsewhere on the board
/Expansion Slots/EA17: J501.c14, J502.c14, J503.c14, J504.c14; also elsewhere on the board
/Expansion Slots/EA18: J501.c15, J502.c15, J503.c15, J504.c15; also elsewhere on the board
/Expansion Slots/EA19: J501.c13, J502.c13, J503.c13, J504.c13; also elsewhere on the board
/Expansion Slots/EA20: J501.a15, J502.a15, J503.a15, J504.a15; also elsewhere on the board
/Expansion Slots/EA21: J501.b14, J502.b14, J503.b14, J504.b14; also elsewhere on the board
/Expansion Slots/EA22: J501.c12, J502.c12, J503.c12, J504.c12; also elsewhere on the board
/Expansion Slots/EA23: J501.a13, J502.a13, J503.a13, J504.a13; also elsewhere on the board
/Expansion Slots/ED0: J501.b11, J502.b11, J503.b11, J504.b11; also elsewhere on the board
/Expansion Slots/ED1: J501.c10, J502.c10, J503.c10, J504.c10; also elsewhere on the board
/Expansion Slots/ED2: J501.a11, J502.a11, J503.a11, J504.a11; also elsewhere on the board
/Expansion Slots/ED3: J501.c9, J502.c9, J503.c9, J504.c9; also elsewhere on the board
/Expansion Slots/ED4: J501.b10, J502.b10, J503.b10, J504.b10; also elsewhere on the board
/Expansion Slots/ED5: J501.b8, J502.b8, J503.b8, J504.b8; also elsewhere on the board
/Expansion Slots/ED6: J501.a9, J502.a9, J503.a9, J504.a9; also elsewhere on the board
/Expansion Slots/ED7: J501.a8, J502.a8, J503.a8, J504.a8; also elsewhere on the board
/Expansion Slots/ED8: J501.b5, J502.b5, J503.b5, J504.b5; also elsewhere on the board
/Expansion Slots/ED9: J501.a6, J502.a6, J503.a6, J504.a6; also elsewhere on the board
/Expansion Slots/ED10: J501.a7, J502.a7, J503.a7, J504.a7; also elsewhere on the board
/Expansion Slots/ED11: J501.b6, J502.b6, J503.b6, J504.b6; also elsewhere on the board
/Expansion Slots/ED12: J501.c7, J502.c7, J503.c7, J504.c7; also elsewhere on the board
/Expansion Slots/ED13: J501.c5, J502.c5, J503.c5, J504.c5; also elsewhere on the board
/Expansion Slots/ED14: J501.b7, J502.b7, J503.b7, J504.b7; also elsewhere on the board
/Expansion Slots/ED15: J501.c6, J502.c6, J503.c6, J504.c6; also elsewhere on the board
/Expansion Slots/EFC0: J501.b25, J502.b25, J503.b25, J504.b25; also elsewhere on the board
/Expansion Slots/EFC1: J501.a25, J502.a25, J503.a25, J504.a25; also elsewhere on the board
/Expansion Slots/EFC2: J501.c25, J502.c25, J503.c25, J504.c25; also elsewhere on the board
/Expansion Slots/ER/~W: J501.a22, J502.a22, J503.a22, J504.a22; also elsewhere on the board
/Expansion Slots/I2C_SCL0: J501.a3
/Expansion Slots/I2C_SCL1: J503.a3
/Expansion Slots/I2C_SCL2: J504.a3
/Expansion Slots/I2C_SCL3: J502.a3
/Expansion Slots/I2C_SDA0: J501.c3
/Expansion Slots/I2C_SDA1: J503.c3
/Expansion Slots/I2C_SDA2: J504.c3
/Expansion Slots/I2C_SDA3: J502.c3
/Expansion Slots/Slots 1-4/CLK: J501.a24, J502.a24, J503.a24, J504.a24
/Expansion Slots/Slots 1-4/SNDL0: J501.c32
/Expansion Slots/Slots 1-4/SNDL1: J503.c32
/Expansion Slots/Slots 1-4/SNDL2: J502.c32
/Expansion Slots/Slots 1-4/SNDL3: J504.c32
/Expansion Slots/Slots 1-4/SNDR0: J501.a32
/Expansion Slots/Slots 1-4/SNDR1: J503.a32
/Expansion Slots/Slots 1-4/SNDR2: J502.a32
/Expansion Slots/Slots 1-4/SNDR3: J504.a32
/Expansion Slots/Slots 1-4/~IRQ_IN_1: J501.a27
/Expansion Slots/Slots 1-4/~IRQ_OUT_1: J501.a28, J503.a27
/Expansion Slots/Slots 1-4/~IRQ_OUT_2: J503.a28, J504.a27
/Expansion Slots/Slots 1-4/~IRQ_OUT_3: J502.a27, J504.a28
/Expansion Slots/~EAS: J501.c23, J502.c23, J503.c23, J504.c23; also elsewhere on the board
/Expansion Slots/~ELDS: J501.b22, J502.b22, J503.b22, J504.b22; also elsewhere on the board
/Expansion Slots/~EUDS: J501.c22, J502.c22, J503.c22, J504.c22; also elsewhere on the board
/Expansion Slots/~I2C_IRQ0: J501.b3
/Expansion Slots/~I2C_IRQ1: J503.b3
/Expansion Slots/~I2C_IRQ2: J504.b3
/Expansion Slots/~I2C_IRQ3: J502.b3
/Expansion Slots/~IRQ_OUT: J502.a28; also elsewhere on the board
/~BERR: J501.c30, J502.c30, J503.c30, J504.c30; also elsewhere on the board
/~BGACK: J501.c29, J502.c29, J503.c29, J504.c29; also elsewhere on the board
/~BG: J501.b28, J502.b28, J503.b28, J504.b28; also elsewhere on the board
/~BR: J501.b29, J502.b29, J503.b29, J504.b29; also elsewhere on the board
/~DETECT0: J501.b27; also elsewhere on the board
/~DETECT1: J503.b27; also elsewhere on the board
/~DETECT2: J504.b27; also elsewhere on the board
/~DETECT3: J502.b27; also elsewhere on the board
/~DTACK: J501.b23, J502.b23, J503.b23, J504.b23; also elsewhere on the board
/~HALT: J501.c28, J502.c28, J503.c28, J504.c28; also elsewhere on the board
/~IACK: J501.a30, J502.a30, J503.a30, J504.a30; also elsewhere on the board
/~IRQ: J501.b30, J502.b30, J503.b30, J504.b30; also elsewhere on the board
/~RESET: J501.a29, J502.a29, J503.a29, J504.a29; also elsewhere on the board
GND: C501.2, C502.2, C503.2, C504.2, C505.2, C506.2, C507.2, C508.2, C509.2, C510.2, C511.2, C512.2, C513.2, C514.2, C515.2, C516.2, C517.2, C518.2, J501.a4, J501.a5, J501.a10, J501.a12, J501.a14, J501.a19, J501.a23, J501.a31, J501.b1, J501.b2, J501.b4, J501.b9, J501.b12, J501.b13, J501.b18, J501.b24, J501.b31, J501.b32, J501.c4, J501.c8, J501.c11, J501.c17, J501.c27, J501.c31, J502.a4, J502.a5, J502.a10, J502.a12, J502.a14, J502.a19, J502.a23, J502.a31, J502.b1, J502.b2, J502.b4, J502.b9, J502.b12, J502.b13, J502.b18, J502.b24, J502.b31, J502.b32, J502.c4, J502.c8, J502.c11, J502.c17, J502.c27, J502.c31, J503.a4, J503.a5, J503.a10, J503.a12, J503.a14, J503.a19, J503.a23, J503.a31, J503.b1, J503.b2, J503.b4, J503.b9, J503.b12, J503.b13, J503.b18, J503.b24, J503.b31, J503.b32, J503.c4, J503.c8, J503.c11, J503.c17, J503.c27, J503.c31, J504.a4, J504.a5, J504.a10, J504.a12, J504.a14, J504.a19, J504.a23, J504.a31, J504.b1, J504.b2, J504.b4, J504.b9, J504.b12, J504.b13, J504.b18, J504.b24, J504.b31, J504.b32, J504.c4, J504.c8, J504.c11, J504.c17, J504.c27, J504.c31; also elsewhere on the board

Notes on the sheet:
One 10µF/100nF per slot
Shared between all 4 slots


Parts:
C601, C610: 47µF; CP_Elec_6.3x5.7; MPN A768EB476M1ELAS042
C602, C604: 10µF; CP_Radial_D4.0mm_P1.50mm; MPN ESY106M035AB2AA
C603, C605: 10µF; CP_EIA-3216-18_Kemet-A; MPN TAJA106K016RNJV
C606, C607, C608, C609: 100nF; C_0805_2012Metric
J601: Slot 5; DIN41612_C_3x32_Female_Vertical_THT; MPN 86093968124H55V1LF
J602: Slot 6; DIN41612_C_3x32_Female_Vertical_THT; MPN 86093968124H55V1LF

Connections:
+5V: C601.1, C603.1, C605.1, C607.1, C609.1, J601.a1, J601.a2, J602.a1, J602.a2; also elsewhere on the board
+12V: C602.1, C604.1, C606.1, C608.1, C610.1, J601.c1, J601.c2, J602.c1, J602.c2; also elsewhere on the board
/Expansion Slots/EA1: J601.c21, J602.c21; also elsewhere on the board
/Expansion Slots/EA2: J601.c20, J602.c20; also elsewhere on the board
/Expansion Slots/EA3: J601.b21, J602.b21; also elsewhere on the board
/Expansion Slots/EA4: J601.b20, J602.b20; also elsewhere on the board
/Expansion Slots/EA5: J601.a21, J602.a21; also elsewhere on the board
/Expansion Slots/EA6: J601.c19, J602.c19; also elsewhere on the board
/Expansion Slots/EA7: J601.a20, J602.a20; also elsewhere on the board
/Expansion Slots/EA8: J601.c18, J602.c18; also elsewhere on the board
/Expansion Slots/EA9: J601.b19, J602.b19; also elsewhere on the board
/Expansion Slots/EA10: J601.b17, J602.b17; also elsewhere on the board
/Expansion Slots/EA11: J601.a18, J602.a18; also elsewhere on the board
/Expansion Slots/EA12: J601.c16, J602.c16; also elsewhere on the board
/Expansion Slots/EA13: J601.a16, J602.a16; also elsewhere on the board
/Expansion Slots/EA14: J601.a17, J602.a17; also elsewhere on the board
/Expansion Slots/EA15: J601.b15, J602.b15; also elsewhere on the board
/Expansion Slots/EA16: J601.b16, J602.b16; also elsewhere on the board
/Expansion Slots/EA17: J601.c14, J602.c14; also elsewhere on the board
/Expansion Slots/EA18: J601.c15, J602.c15; also elsewhere on the board
/Expansion Slots/EA19: J601.c13, J602.c13; also elsewhere on the board
/Expansion Slots/EA20: J601.a15, J602.a15; also elsewhere on the board
/Expansion Slots/EA21: J601.b14, J602.b14; also elsewhere on the board
/Expansion Slots/EA22: J601.c12, J602.c12; also elsewhere on the board
/Expansion Slots/EA23: J601.a13, J602.a13; also elsewhere on the board
/Expansion Slots/ED0: J601.b11, J602.b11; also elsewhere on the board
/Expansion Slots/ED1: J601.c10, J602.c10; also elsewhere on the board
/Expansion Slots/ED2: J601.a11, J602.a11; also elsewhere on the board
/Expansion Slots/ED3: J601.c9, J602.c9; also elsewhere on the board
/Expansion Slots/ED4: J601.b10, J602.b10; also elsewhere on the board
/Expansion Slots/ED5: J601.b8, J602.b8; also elsewhere on the board
/Expansion Slots/ED6: J601.a9, J602.a9; also elsewhere on the board
/Expansion Slots/ED7: J601.a8, J602.a8; also elsewhere on the board
/Expansion Slots/ED8: J601.b5, J602.b5; also elsewhere on the board
/Expansion Slots/ED9: J601.a6, J602.a6; also elsewhere on the board
/Expansion Slots/ED10: J601.a7, J602.a7; also elsewhere on the board
/Expansion Slots/ED11: J601.b6, J602.b6; also elsewhere on the board
/Expansion Slots/ED12: J601.c7, J602.c7; also elsewhere on the board
/Expansion Slots/ED13: J601.c5, J602.c5; also elsewhere on the board
/Expansion Slots/ED14: J601.b7, J602.b7; also elsewhere on the board
/Expansion Slots/ED15: J601.c6, J602.c6; also elsewhere on the board
/Expansion Slots/EFC0: J601.b25, J602.b25; also elsewhere on the board
/Expansion Slots/EFC1: J601.a25, J602.a25; also elsewhere on the board
/Expansion Slots/EFC2: J601.c25, J602.c25; also elsewhere on the board
/Expansion Slots/ER/~W: J601.a22, J602.a22; also elsewhere on the board
/Expansion Slots/I2C_SCL4: J601.a3
/Expansion Slots/I2C_SCL5: J602.a3
/Expansion Slots/I2C_SDA4: J601.c3
/Expansion Slots/I2C_SDA5: J602.c3
/Expansion Slots/Slots 5-6/CLK: J601.a24, J602.a24
/Expansion Slots/Slots 5-6/SNDL4: J601.c32
/Expansion Slots/Slots 5-6/SNDL5: J602.c32
/Expansion Slots/Slots 5-6/SNDR4: J601.a32
/Expansion Slots/Slots 5-6/SNDR5: J602.a32
/Expansion Slots/Slots 5-6/~IRQ_OUT_5: J601.a28, J602.a27
/Expansion Slots/Slots 5-6/~IRQ_OUT_6: J602.a28
/Expansion Slots/~EAS: J601.c23, J602.c23; also elsewhere on the board
/Expansion Slots/~ELDS: J601.b22, J602.b22; also elsewhere on the board
/Expansion Slots/~EUDS: J601.c22, J602.c22; also elsewhere on the board
/Expansion Slots/~I2C_IRQ4: J601.b3
/Expansion Slots/~I2C_IRQ5: J602.b3
/Expansion Slots/~IRQ_OUT: J601.a27; also elsewhere on the board
/~BERR: J601.c30, J602.c30; also elsewhere on the board
/~BGACK: J601.c29, J602.c29; also elsewhere on the board
/~BG: J601.b28, J602.b28; also elsewhere on the board
/~BR: J601.b29, J602.b29; also elsewhere on the board
/~DETECT4: J601.b27; also elsewhere on the board
/~DETECT5: J602.b27; also elsewhere on the board
/~DTACK: J601.b23, J602.b23; also elsewhere on the board
/~HALT: J601.c28, J602.c28; also elsewhere on the board
/~IACK: J601.a30, J602.a30; also elsewhere on the board
/~IRQ: J601.b30, J602.b30; also elsewhere on the board
/~RESET: J601.a29, J602.a29; also elsewhere on the board
GND: C601.2, C602.2, C603.2, C604.2, C605.2, C606.2, C607.2, C608.2, C609.2, C610.2, J601.a4, J601.a5, J601.a10, J601.a12, J601.a14, J601.a19, J601.a23, J601.a31, J601.b1, J601.b2, J601.b4, J601.b9, J601.b12, J601.b13, J601.b18, J601.b24, J601.b31, J601.b32, J601.c4, J601.c8, J601.c11, J601.c17, J601.c27, J601.c31, J602.a4, J602.a5, J602.a10, J602.a12, J602.a14, J602.a19, J602.a23, J602.a31, J602.b1, J602.b2, J602.b4, J602.b9, J602.b12, J602.b13, J602.b18, J602.b24, J602.b31, J602.b32, J602.c4, J602.c8, J602.c11, J602.c17, J602.c27, J602.c31; also elsewhere on the board

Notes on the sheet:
Shared between all slots
One 10µF/100nF per slot

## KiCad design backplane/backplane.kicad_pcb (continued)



Board: 4 copper layers, 215.0 x 129.0 mm, 79 parts (10 on the bottom side), 132 nets.

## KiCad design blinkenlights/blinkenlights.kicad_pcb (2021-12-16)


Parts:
C401, C402, C403, C404, C407, C410: 10µF; CP_EIA-3216-18_Kemet-A; MPN TAJB106K025SNJ
C405, C406, C408, C409, C411, C412, C413, C414, C415, C416, C417, C418, C419, C420, C421, C422, C423, C424, C425, C426: 100nF; C_0805_2012Metric
D401, D402: Yellow; LED_0805_2012Metric; MPN AP2012YD
DIS401, DIS402, DIS403, DIS404, DIS405, DIS406, DIS407, DIS408, DIS409, DIS410: TIL311
R401, R402: 0R; R_0805_2012Metric; MPN RC0805JR-100RL
R409, R410: 1k; R_0805_2012Metric
U402: 74LVC2G34; SOT-363_SC-70-6_Handsoldering; MPN 74LVC2G34DW-7

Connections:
+5V: C401.1, C402.1, C403.1, C406.1, C409.1, C412.1, C414.1, C416.1, C418.1, C420.1, C422.1, C424.1, C426.1, DIS401.14 (Vcc_logic), DIS402.14 (Vcc_logic), DIS403.14 (Vcc_logic), DIS404.14 (Vcc_logic), DIS405.14 (Vcc_logic), DIS406.14 (Vcc_logic), DIS407.14 (Vcc_logic), DIS408.14 (Vcc_logic), DIS409.14 (Vcc_logic), DIS410.14 (Vcc_logic), U402.5 (VCC); also elsewhere on the board
+5VA: C404.1, C405.1, C407.1, C408.1, C410.1, C411.1, C413.1, C415.1, C417.1, C419.1, C421.1, C423.1, C425.1, DIS401.1 (Vcc_LED), DIS402.1 (Vcc_LED), DIS403.1 (Vcc_LED), DIS404.1 (Vcc_LED), DIS405.1 (Vcc_LED), DIS406.1 (Vcc_LED), DIS407.1 (Vcc_LED), DIS408.1 (Vcc_LED), DIS409.1 (Vcc_LED), DIS410.1 (Vcc_LED); also elsewhere on the board
/A1: DIS406.2 (B); also elsewhere on the board
/A2: DIS406.13 (C); also elsewhere on the board
/A3: DIS406.12 (D); also elsewhere on the board
/A4: DIS405.3 (A); also elsewhere on the board
/A5: DIS405.2 (B); also elsewhere on the board
/A6: DIS405.13 (C); also elsewhere on the board
/A7: DIS405.12 (D); also elsewhere on the board
/A8: DIS404.3 (A); also elsewhere on the board
/A9: DIS404.2 (B); also elsewhere on the board
/A10: DIS404.13 (C); also elsewhere on the board
/A11: DIS404.12 (D); also elsewhere on the board
/A12: DIS403.3 (A); also elsewhere on the board
/A13: DIS403.2 (B); also elsewhere on the board
/A14: DIS403.13 (C); also elsewhere on the board
/A15: DIS403.12 (D); also elsewhere on the board
/A16: DIS402.3 (A); also elsewhere on the board
/A17: DIS402.2 (B); also elsewhere on the board
/A18: DIS402.13 (C); also elsewhere on the board
/A19: DIS402.12 (D); also elsewhere on the board
/A20: DIS401.3 (A); also elsewhere on the board
/A21: DIS401.2 (B); also elsewhere on the board
/A22: DIS401.13 (C); also elsewhere on the board
/A23: DIS401.12 (D); also elsewhere on the board
/D0: DIS410.3 (A); also elsewhere on the board
/D1: DIS410.2 (B); also elsewhere on the board
/D2: DIS410.13 (C); also elsewhere on the board
/D3: DIS410.12 (D); also elsewhere on the board
/D4: DIS409.3 (A); also elsewhere on the board
/D5: DIS409.2 (B); also elsewhere on the board
/D6: DIS409.13 (C); also elsewhere on the board
/D7: DIS409.12 (D); also elsewhere on the board
/D8: DIS408.3 (A); also elsewhere on the board
/D9: DIS408.2 (B); also elsewhere on the board
/D10: DIS408.13 (C); also elsewhere on the board
/D11: DIS408.12 (D); also elsewhere on the board
/D12: DIS407.3 (A); also elsewhere on the board
/D13: DIS407.2 (B); also elsewhere on the board
/D14: DIS407.13 (C); also elsewhere on the board
/D15: DIS407.12 (D); also elsewhere on the board
/Displays and Indicators/BLANK_ADDR: DIS401.8 (Blanking_Input), DIS402.8 (Blanking_Input), DIS403.8 (Blanking_Input), DIS404.8 (Blanking_Input), DIS405.8 (Blanking_Input), DIS406.8 (Blanking_Input), R401.2
/Displays and Indicators/BLANK_DATA: DIS407.8 (Blanking_Input), DIS408.8 (Blanking_Input), DIS409.8 (Blanking_Input), DIS410.8 (Blanking_Input), R402.2
/Displays and Indicators/~DATA_LATCH: DIS407.5 (/Latch_Strobe_Input), DIS408.5 (/Latch_Strobe_Input), DIS409.5 (/Latch_Strobe_Input), DIS410.5 (/Latch_Strobe_Input)
/~AS: DIS401.5 (/Latch_Strobe_Input), DIS402.5 (/Latch_Strobe_Input), DIS403.5 (/Latch_Strobe_Input), DIS404.5 (/Latch_Strobe_Input), DIS405.5 (/Latch_Strobe_Input), DIS406.5 (/Latch_Strobe_Input); also elsewhere on the board
/~HALT: U402.3; also elsewhere on the board
/~RESET: U402.1; also elsewhere on the board
GND: C401.2, C402.2, C403.2, C404.2, C405.2, C406.2, C407.2, C408.2, C409.2, C410.2, C411.2, C412.2, C413.2, C414.2, C415.2, C416.2, C417.2, C418.2, C419.2, C420.2, C421.2, C422.2, C423.2, C424.2, C425.2, C426.2, D401.1 (K), D402.1 (K), DIS401.7 (GND), DIS402.7 (GND), DIS403.7 (GND), DIS404.7 (GND), DIS405.7 (GND), DIS406.3 (A), DIS406.7 (GND), DIS407.7 (GND), DIS408.7 (GND), DIS409.7 (GND), DIS410.7 (GND), R401.1, R402.1, U402.2 (GND); also elsewhere on the board
unnamed: D401.2 (A), R409.2
unnamed: D402.2 (A), R410.2
unnamed: R409.1, U402.6
unnamed: R410.1, U402.4

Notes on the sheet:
1x 10µF per 3ish displays
1x 100nF per display
For address displays
For data displays
Do not blank the displays, ever


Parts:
C501, C502, C503, C504, C505, C507, C509, C511: 100nF; C_0805_2012Metric
C506, C508, C512: 4.7µF; C_0805_2012Metric
C514: 10µF; CP_EIA-3216-18_Kemet-A; MPN TAJB106K025SNJ
R501, R504: 200k; R_0805_2012Metric
R502, R503: 10k; R_0805_2012Metric
U501, U503, U505: XRA1403; TSSOP-24_4.4x7.8mm_P0.65mm
U502: PCA9306DP; SO-8_3.9x4.9mm_P1.27mm
U504: XRA1402; TSSOP-16_4.4x5mm_P0.65mm
U506: Teensy4.0; Teensy40-NoBonus
U507: 74LVC2G06; SOT-23-6_Handsoldering
U508, U509: 74LVC2T45DC; VSSOP-8_2.3x2mm_P0.5mm

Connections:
+3V3: C501.1, C502.1, C504.1, C505.1, C506.1, C507.1, C508.1, C509.1, C511.1, C512.1, C514.1, R502.2, R503.2, U501.24 (VCC), U502.2 (VREF1), U503.24 (VCC), U504.16 (VCC), U505.24 (VCC), U506.31 (3V3), U507.5 (VCC), U508.1 (VCCA), U509.1 (VCCA); also elsewhere on the board
+5V: C503.1, R501.2, R504.2, U506.33 (VIN), U508.8 (VCCB), U509.8 (VCCB); also elsewhere on the board
/A1: U503.4 (P0); also elsewhere on the board
/A2: U503.5 (P1); also elsewhere on the board
/A3: U503.6 (P2); also elsewhere on the board
/A4: U503.7 (P3); also elsewhere on the board
/A5: U503.8 (P4); also elsewhere on the board
/A6: U503.9 (P5); also elsewhere on the board
/A7: U503.10 (P6); also elsewhere on the board
/A8: U503.11 (P7); also elsewhere on the board
/A9: U503.13 (P8); also elsewhere on the board
/A10: U503.14 (P9); also elsewhere on the board
/A11: U503.15 (P10); also elsewhere on the board
/A12: U503.16 (P11); also elsewhere on the board
/A13: U503.17 (P12); also elsewhere on the board
/A14: U503.18 (P13); also elsewhere on the board
/A15: U503.19 (P14); also elsewhere on the board
/A16: U503.20 (P15); also elsewhere on the board
/A17: U504.4 (P0); also elsewhere on the board
/A18: U504.5 (P1); also elsewhere on the board
/A19: U504.6 (P2); also elsewhere on the board
/A20: U504.7 (P3); also elsewhere on the board
/A21: U504.9 (P4); also elsewhere on the board
/A22: U504.10 (P5); also elsewhere on the board
/A23: U504.11 (P6); also elsewhere on the board
/D0: U501.4 (P0); also elsewhere on the board
/D1: U501.5 (P1); also elsewhere on the board
/D2: U501.6 (P2); also elsewhere on the board
/D3: U501.7 (P3); also elsewhere on the board
/D4: U501.8 (P4); also elsewhere on the board
/D5: U501.9 (P5); also elsewhere on the board
/D6: U501.10 (P6); also elsewhere on the board
/D7: U501.11 (P7); also elsewhere on the board
/D8: U501.13 (P8); also elsewhere on the board
/D9: U501.14 (P9); also elsewhere on the board
/D10: U501.15 (P10); also elsewhere on the board
/D11: U501.16 (P11); also elsewhere on the board
/D12: U501.17 (P12); also elsewhere on the board
/D13: U501.18 (P13); also elsewhere on the board
/D14: U501.19 (P14); also elsewhere on the board
/D15: U501.20 (P15); also elsewhere on the board
/I2C_SCL: U502.6 (SCL2); also elsewhere on the board
/I2C_SDA: U502.5 (SDA2); also elsewhere on the board
/IO Drivers/ASSERT_HALT: U506.21 (14_A0_TX3_SPDIF_OUT), U507.1
/IO Drivers/CTRL_DIR: U506.29 (22_A8_CTX1), U509.5 (DIR)
/IO Drivers/MISO: U501.23 (MISO), U503.23 (MISO), U504.15 (MISO), U505.23 (MISO), U506.14 (12_MISO_MQSL)
/IO Drivers/MOSI: U501.2 (MOSI), U503.2 (MOSI), U504.2 (MOSI), U505.2 (MOSI), U506.13 (11_MOSI_CTX1)
/IO Drivers/R/~W_3V3: U506.27 (20_A6_TX5_LRCLK1), U509.2 (1A)
/IO Drivers/SCK: U501.22 (SCK), U503.22 (SCK), U504.14 (SCK), U505.22 (SCK), U506.20 (13_SCK_CRX1_LED)
/IO Drivers/SCL: R503.1, U502.3 (SCL1), U506.26 (19_A5_SCL0)
/IO Drivers/SDA: R502.1, U502.4 (SDA1), U506.25 (18_A4_SDA0)
/IO Drivers/~AS_3V3: U506.28 (21_A7_RX5_BCLK1), U509.3 (2A)
/IO Drivers/~BERR_3V3: U506.7 (5_IN2), U508.2 (1A)
/IO Drivers/~DTACK_3V3: U506.8 (6_OUT1D), U508.3 (2A)
/IO Drivers/~I2C_BUF_DIS: R504.1, U502.8 (EN), U505.13 (P8)
/IO Drivers/~IO1_CS: U501.21 (~CS), U506.9 (7_RX2_OUT1A)
/IO Drivers/~IO2_CS: U503.21 (~CS), U506.10 (8_TX2_IN1)
/IO Drivers/~IO3_CS: U504.1 (~CS), U506.11 (9_OUT1C)
/IO Drivers/~IO4_CS: U505.21 (~CS), U506.12 (10_CS_MQSR)
/IO Drivers/~TST_IRQ: U501.1 (~IRQ), U503.1 (~IRQ), U504.13 (~IRQ), U505.1 (~IRQ), U506.23 (16_A2_RX4_SCL1)
/IO Drivers/~TST_RESET: U501.3 (~RESET), U503.3 (~RESET), U504.3 (~RESET), U505.3 (~RESET), U506.24 (17_A3_TX4_SDA1)
/R/~W: U505.15 (P10), U509.7 (1B); also elsewhere on the board
/~AS: U505.19 (P14), U509.6 (2B); also elsewhere on the board
/~BERR: U505.6 (P2), U508.7 (1B); also elsewhere on the board
/~BGACK: U505.9 (P5); also elsewhere on the board
/~BG: U505.11 (P7); also elsewhere on the board
/~BR: U505.8 (P4); also elsewhere on the board
/~DTACK: U505.18 (P13), U508.6 (2B); also elsewhere on the board
/~HALT: U505.20 (P15), U507.6; also elsewhere on the board
/~I2C_IRQ: U505.14 (P9); also elsewhere on the board
/~IACK: U505.4 (P0); also elsewhere on the board
/~IRQ: U505.5 (P1); also elsewhere on the board
/~LDS: U505.16 (P11); also elsewhere on the board
/~MEM: U505.10 (P6); also elsewhere on the board
/~RESET: U505.7 (P3); also elsewhere on the board
/~UDS: U505.17 (P12); also elsewhere on the board
GND: C501.2, C502.2, C503.2, C504.2, C505.2, C506.2, C507.2, C508.2, C509.2, C511.2, C512.2, C514.2, U501.12 (GND), U502.1 (GND), U503.12 (GND), U504.8 (GND), U505.12 (GND), U506.1 (GND), U506.17 (GND), U506.32 (GND), U506.47 (GND), U507.2 (GND), U507.3, U508.4 (GND), U508.5 (DIR), U509.4 (GND); also elsewhere on the board
unnamed: R501.1, U502.7 (VREF2)

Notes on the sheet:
NOTE: Teensy MUST be modified to support simultaneous +5V and VBUS supply!
Sprinkle around
~{IO1_CS}: Data bus ~{IO2_CS}: Address bus (low), ~{IO3_CS}: Address bus (high) ~{IO4_CS}: Control signals
One pair per IO expander


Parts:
C301, C310, C313, C316: 100nF; C_0805_2012Metric
C302: 4.7µF; C_0805_2012Metric
C304, C311, C317: 22µF; CP_EIA-3528-21_Kemet-B; MPN TAJB226K016UNJ
C306: 47µF; CP_Radial_D6.3mm_P2.50mm; MPN A750EK476M1EAAE040
C309: 10µF; CP_EIA-3528-21_Kemet-B; MPN TAJB106K025SNJ
C312: 4700pF; C_0805_2012Metric
D301, D302, D303, D304: Green; LED_0805_2012Metric; MPN 150080GS75000
F301: 1.1A; Fuse_Bourns_MF-SM_7.98x5.44mm; MPN 652-MFSM100-2
J301, J302, J303: Conn_01x01_Female; DELTRON-571-0x00
L302: 4.7µH; L_Taiyo-Yuden_NR-80xx_HandSoldering; MPN NRS8040T4R7NJGJ
R303, R307: 300R; R_0805_2012Metric
R304: 4k7; R_0805_2012Metric
R305: 4k3; R_0805_2012Metric
R306: 820R; R_0805_2012Metric
R308: 120R; R_0805_2012Metric
R309: 12k; R_0805_2012Metric
U301: BD9C301FJ; SOP-8_3.9x4.9mm_P1.27mm

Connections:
+3V3: C316.1, C317.1, R308.1; also elsewhere on the board
+5V: C304.1, C311.1, C313.1, F301.2, J302.1, L302.2, R303.1, R305.1; also elsewhere on the board
+5VA: C301.1, C302.1, F301.1, R307.1; also elsewhere on the board
+12V: C306.1, C309.1, C310.1, J301.1, R304.1, U301.2 (VIN), U301.6 (EN); also elsewhere on the board
GND: C301.2, C302.2, C304.2, C306.2, C309.2, C310.2, C311.2, C312.1, C313.2, C316.2, C317.2, D301.1 (K), D302.1 (K), D303.1 (K), D304.1 (K), J303.1, R306.2, U301.1 (PGND), U301.3 (AGND); also elsewhere on the board
unnamed: C312.2, R309.1
unnamed: D301.2 (A), R303.2
unnamed: D302.2 (A), R304.2
unnamed: D303.2 (A), R307.2
unnamed: D304.2 (A), R308.2
unnamed: L302.1, U301.7 (SW), U301.8 (SW)
unnamed: R305.2, R306.1, U301.4 (FB)
unnamed: R309.2, U301.5 (COMP)

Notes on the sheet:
+5V: Logic and +5V supply to CPU board
+3V3: Microcontroller
Provided by Teensy
+5VA: For LEDs, indicators, etc


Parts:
C201: 10µF; CP_EIA-3216-18_Kemet-A; MPN TAJB106K025SNJ
C202, C205: 1µF; C_0805_2012Metric
C203, C206: 100nF; C_0805_2012Metric
C204: 10µF; CP_EIA-3528-21_Kemet-B; MPN TAJB106K025SNJ
F201: 1.5A; Fuse_Bourns_MF-SM_7.98x5.44mm; MPN MF-SM150/33-2
F202: .5A; Fuse_Littelfuse-NANO2-451_453; MPN NANOSMDC050F/13.2-2
J201: Conn_03x32_Row_Letter_First; DIN41612_C_3x32_Female_Vertical_THT
J202, J203, J204, J205: Conn_02x20_Odd_Even; PinHeader_2x18_P2.54mm_Vertical
TP201, TP202, TP203, TP204, TP205, TP206, TP207, TP208: TestPoint; TestPoint_Loop_D2.60mm_Drill1.4mm_Beaded; MPN 534-5001
U201: AT24CS32-SSHM; SOIC-8_3.9x4.9mm_P1.27mm; MPN AT24CS32-SSHM-T
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

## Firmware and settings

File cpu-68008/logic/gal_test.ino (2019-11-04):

/**
 * Sets up the IO ports.
 */
void setup() {
  // enable serial
   Serial.begin(115200);
  
  // FC2-FC0
  pinMode(24, OUTPUT);
  digitalWrite(24, HIGH);
  pinMode(25, OUTPUT);
  digitalWrite(25, HIGH);
  pinMode(26, OUTPUT);
  digitalWrite(26, HIGH);

  // R/!W
  pinMode(27, OUTPUT);
  digitalWrite(27, HIGH);
  // !AS
  pinMode(28, OUTPUT);
  digitalWrite(28, HIGH);

  // A15-A19
  pinMode(29, OUTPUT);
  digitalWrite(29, HIGH);
  pinMode(30, OUTPUT);
  digitalWrite(30, HIGH);
  pinMode(31, OUTPUT);
  digitalWrite(31, HIGH);
  pinMode(32, OUTPUT);
  digitalWrite(32, HIGH);
  pinMode(33, OUTPUT);
  digitalWrite(33, HIGH);

  // chip selects
  pinMode(34, INPUT); // 68681
  pinMode(35, INPUT); // RTC
  pinMode(36, INPUT); // RAM
  pinMode(37, INPUT); // ROM
  pinMode(43, INPUT); // Bus

  // strobes
  pinMode(38, INPUT); // !OE
  pinMode(39, INPUT); // !IACK
  pinMode(40, INPUT); // !REQUIRE_DTACK

  // bus error timer
  pinMode(42, INPUT); // !BERR_TIMER_CLEAR
}

/**
 * Sets up the state of the bus lines.
 */
void setUpBus(uint8_t fc, bool addrValid, uint32_t addr, bool isWrite, bool log = false) {
   // set function code
  digitalWrite(24, (fc & 0x4) ? HIGH : LOW);
  digitalWrite(25, (fc & 0x2) ? HIGH : LOW);
  digitalWrite(26, (fc & 0x1) ? HIGH : LOW);

  // control R/!W and !AS
  digitalWrite(27, isWrite ? LOW : HIGH);
  digitalWrite(28, addrValid ? LOW : HIGH);

  // the address bits
  uint8_t addrBits = (addr >> 15);

//  Serial.print("Address: ");
//  Serial.println(addr);
//  Serial.print("Bits: ");
//  Serial.println(addrBits);
  
  digitalWrite(29, (addrBits & 0x1) ? HIGH : LOW);
  digitalWrite(30, (addrBits & 0x2) ? HIGH : LOW);
  digitalWrite(31, (addrBits & 0x4) ? HIGH : LOW);
  digitalWrite(32, (addrBits & 0x8) ? HIGH : LOW);
  digitalWrite(33, (addrBits & 0x10) ? HIGH : LOW);

  // write what we did
  if(log) {
    Serial.print("\tAddress: $");
    Serial.print(addr, HEX);
    
    Serial.print("; FC: $");
    Serial.print(fc, HEX);
    
    Serial.print("; AS: ");
    Serial.print(addrValid ? "Asserted" : "Deasserted");
    
    Serial.print("; R/W: ");
    Serial.println(isWrite ? "Write (Asserted)" : "Read (Deasserted)");
  }
}

/**
 * Reads and prints the state of the outputs.
 */
void readOutputs() {
  // read chip selects
  Serial.println("\tChip Selects");
  
  // 68681 CS
  Serial.print("\t\t68681: ");
  Serial.println((digitalRead(34) == HIGH) ? "Deasserted" : "Asserted");
  // RTC CS
  Serial.print("\t\tRTC: ");
  Serial.println((digitalRead(35) == HIGH) ? "Deasserted" : "Asserted");
  // RAM CS
  Serial.print("\t\tRAM: ");
  Serial.println((digitalRead(36) == HIGH) ? "Deasserted" : "Asserted");
  // ROM CS
  Serial.print("\t\tROM: ");
  Serial.println((digitalRead(37) == HIGH) ? "Deasserted" : "Asserted");
  // Bus CS
  Serial.print("\t\tExpansion Bus: ");
  Serial.println((digitalRead(43) == HIGH) ? "Deasserted" : "Asserted");


  // strobes
  Serial.println("\tStrobes");
  
  Serial.print("\t\t!OE: ");
  Serial.println((digitalRead(38) == HIGH) ? "Deasserted" : "Asserted");
  Serial.print("\t\tIACK: ");
  Serial.println((digitalRead(39) == HIGH) ? "Deasserted" : "Asserted");
  Serial.print("\t\tREQUIRE_DTACK: ");
  Serial.println((digitalRead(40) == HIGH) ? "Deasserted" : "Asserted");
  Serial.print("\t\tBERR_TIMER_CLR: ");
  Serial.println((digitalRead(42) == HIGH) ? "Deasserted\n" : "Asserted\n");
}

/**
 * Does a bus cycle or whatever the fuck
 */
void doBusCycle(uint32_t addr) {
  // set up for a read
  setUpBus(5, false, addr, false);
  setUpBus(5, true, addr, false, true);

  readOutputs();

  setUpBus(5, false, addr, false);

  // set up for a write
  setUpBus(5, false, addr, true);
  setUpBus(5, true, addr, true, true);

  readOutputs();

  setUpBus(5, false, addr, true);
}

void loop() {
  // the addresses we want to test
  const static uint32_t kAddresses[] = {
    // ROM
    0x00000,
    0x08000,
    0x10000,

    // 68681
    0x20000,
    // RTC/NVRAM
    0x28000,

    // Expansion bus
    0x30000,
    0x40000,
    0x48000,
    0x7F000,

    // RAM
    0x80000,
    0x9F000,
    0xFFFFF,

    // end of list
    0xFFFFFFFF
  };

  // test each one
  int i = 0;

  while(i != -1) {
    auto addr = kAddresses[i];

    if(addr == 0xFFFFFFFF) {
      i = -1;
      break;
    }

    // test it
    Serial.print("\n\nTesting address: $");
    Serial.println(addr, HEX);

    doBusCycle(addr);

    // next one
    i++;
  }


  // meep
  while(1) {}
}

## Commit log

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2018-12-06 removed multifunction peripheral; to be replaced with 68564
    [cpu-68010.brd, cpu-68010.sch]
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2018-12-09 routed remaining signals between SRAM, added decoupling chips and more status LEDs
    [cpu-68010.brd, cpu-68010.sch]
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2019-10-06 replaced CPLD with PLDs
    [cpu-68008.brd, cpu-68008.sch]
2019-10-06 added bus error timeout circuit
    [cpu-68008.brd, cpu-68008.sch]
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2019-10-28 added r/w and reset to backplane; fixed some missing mouser p/n on cpu board
    [backplane.brd, backplane.sch, cpu-68008.brd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]
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2019-10-29 cleaned up routing for sound board a bit, moved some things in preparation of adding midi interface
    [sound.brd, sound.sch]
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2019-11-04 finished routing sound board; added correct CPU board PLDs
    [sound.brd, sound.sch]
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2019-11-04 added /DS to GALs on all peripherals and backplane began work on TMS9918 video card
    [backplane.brd, ide-8bit.sch, sound.brd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]
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2019-11-16 Enlarged 68000 board to 100x160mm (Eurocard size) Moved high/low words sections to accomodate ZIF sockets better
    [cpu-68000.brd, cpu-68000.sch]
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2019-11-17 2MB RAM Expansion: - Added decoding logic - Started routing bus transceivers - Fixed SRAM footprint
    [ram-2mb.brd, ram-2mb.sch]
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2019-11-20 CPU board: - Clean up some traces
    IO board:
    - Started work on super IO board
    - UARTs, parallel port, PS/2 keyboard/mouse interface, I2C
    2MB RAM Expansion:
    - Added some address decoding
    [cpu-68000.brd, cpu-68000.sch, io.brd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]
2019-11-21 IO board: - Added 82C55 PIO
    RAM board:
    - Tweaked tolerances between some traces
    - Fixed naming of parts
    [io.brd, io.sch, ram-2mb.brd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]
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2021-11-12 start pcb for main cpu
    - mostly finish schematic for 68000 cpu; added the missing reset/NMI
    switches
    - added footprints for LED indicators
    - also added 3d models for fuses, DIN connector, etc
    [backplane.kicad_sch, cpu-68000.kicad_pcb, cpu-68000.kicad_sch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]
2021-11-13 Placed most items on pcb
    - Laid out most components where they should go on the board; mostly
    routed the connector side of the bus buffers and the address bus
    - Added 3d models for PLCC sockets, RTC clock module
    [backplane.kicad_sch, cpu-68000.kicad_pcb, cpu-68000.kicad_sch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]
2021-11-14 Begin routing stuff
    - Routed most control signals to GALs, finished routing signals to bus
    transceivers (except data bus)
    - Removed ROMs but doubled up RAM; the boot ROM will be provided by an
    external board
    - Added dual SAA1099 chips (audio out via backplane)
    - Pullups on some external irq/bus request lines
    [backplane.kicad_sch, cpu-68000.kicad_pcb, cpu-68000.kicad_sch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]
2021-11-14 More control signals; start RAM routing
    - Started routing the address/data bus for the RAM, including some
    rejigging of the data bus layout
    - Added a fuse and power conditioning for 12V, to be used for the analog
    section on the sound side
    [backplane.kicad_sch, cpu-68000.kicad_pcb, cpu-68000.kicad_sch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]
2021-11-15 Mostly completed RAM routing
    - Finished routing the address and data busses for RAMs; connected the
    address bus to the 68k, the high byte of data bus is connected but not
    yet low.
    - Connected more control signals to GALs
    - Finished connecting data bus to bus transceivers
    - Fixed clearance setting for traces (matching JLCPCB impedance
    controlled 4 layer stackup)
    [backplane.kicad_sch, cpu-68000.kicad_sch, cpu.kicad_sch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]
2021-11-15 Start peripheral routing
    - Begin routing some of the peripheral section, particularly the NVRAM
    is fully connected (sans chip select) now
    - Added an I2C EEPROM (with serial number) on board the CPU card for
    automatic identification
    - Minor cleanups and space squishing of the board. There may in fact be
    sufficient space to still fit a boot ROM (likely a surface mount
    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
    [cpu-68000.kicad_sch, memory.kicad_sch, peripheral.kicad_sch]
2021-11-16 Mostly finished routing
    - Finished routing most all of the signals, save for a few decoupling
    caps and minor power stuff
    - Do peripheral address decoder with a 3-to-8 decoder, to save a few
    GAL outputs and make routing signals less of a pain in the ass since
    there's less of them
    - Added a write protect jumper for config EEPROM
    [backplane.kicad_sch, cpu-68000.kicad_sch, cpu.kicad_sch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]
2021-11-16 Completed board routing
    - Finished routing all of the signals on the board :D it still needs a
    check over to make sure it's not fucked though
    - Split sound stuff into its own sheet
    [backplane.kicad_sch, cpu-68000.kicad_sch, cpu.kicad_sch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]
2021-11-17 Minor visual fixes to board
    - Used the blank space in the middle of the board for a neat little logo
    or whatever
    [backplane.kicad_sch, cpu-68000.kicad_sch, cpu.kicad_sch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]
2021-11-17 Added memory access type signal
    - Since function codes aren't provided on the backplane, we instead have
    a signal that's driven low to indicate that the access is to memory
    rather than some other type (CPU space). It's open drain with a 10k
    pullup, which is _hopefully_ sufficient.
    [backplane.kicad_sch, cpu-68000.kicad_sch, cpu.kicad_sch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]
2021-11-18 Added I2C mux on cpu board
    - Added an I2C switch that allows switching between the
    identification/config EEPROM on the CPU board, and the bus that's
    external to the board. This avoids address conflicts between external
    peripherals and the CPU board
    [backplane.kicad_sch, cpu-68000.kicad_sch, cpu.kicad_sch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]
2021-11-19 Begin work on blinkenlights board
    - This is a simple board with pretty TIL311 displays for the
    address/data busses, lots of blinking lights, and sockets for boot
    ROMs for testing. It connects directly to the CPU board through a
    female right angle DIN41612 connector.
    - Added footprints for Deltron 571-0x00 test sockets
    [backplane.kicad_sch, blinkenlights.kicad_pcb, blinkenlights.kicad_sch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]
2021-11-23 Start work on blinkenlights pcb
    - This is mostly for the general layout and physical size of the board;
    all the components are placed on the back so the pin numbers will line
    up properly on the DIN connectors.
    [backplane.kicad_sch, blinkenlights.kicad_pcb, blinkenlights.kicad_sch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]
2021-11-30 Tweaks to IOs on 68k board
    - Added an I2C IRQ line, so that I2C peripherals can request servicing.
    This is mostly used for the control panel/backplane management
    functions.
    [backplane.kicad_sch, cpu-68000.kicad_sch, cpu.kicad_sch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]
2021-12-01 Replaced half the RAM for flash (boot ROM)
    Squashed commit of the following:
    commit 629e5dca317ab35f390a35a51af997ba405215d5
    Author: Tristan Seifert <tristan@tseifert.me>
    Date: Tue Nov 30 18:31:19 2021 -0800
    Added high byte flash chip
    - Replaced one of the RAMs with another flash, so that we can have
    on-board boot ROM of 1M. It'll have to be programmed in system (or
    very flimsily out of system before soldering) so a switch to remap the
    flash to elsehwere in the address space is provided (formerly BERR
    inhibit switch)
    commit c59845a042d2b99cf0eb5e3cdf44f56cd0b06346
    Author: Tristan Seifert <tristan@tseifert.me>
    Date: Tue Nov 30 16:27:37 2021 -0800
    F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
    [backplane.kicad_sch, cpu-68000.kicad_sch, cpu.kicad_sch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]
2021-12-01 Added ROM sockets to blinkenlights
    - Also started routing some of the IOs and powers for the displays
    [backplane.kicad_sch, blinkenlights.kicad_pcb, blinkenlights.kicad_sch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]
2021-12-02 Reworked blinkenlights board
    - The connector for the CPU board is a female vertical DIN connector
    instead now, which will be a lot less fucky
    - Some more LEDs and buttons
    [backplane.kicad_sch, blinkenlights.kicad_pcb, blinkenlights.kicad_sch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]
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2021-12-04 Rework blinkenlights board
    - Removed ROMs, GALs and so forth from the blinkenlights board and
    simplified the power distribution significantly. This is in
    preparation for simply placing a big ass microcontroller that allows
    us to perform bus transactions manually (to load bootstrap programs,
    for example) on the system.
    [backplane.kicad_sch, blinkenlights.kicad_pcb, blinkenlights.kicad_sch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]
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2021-12-06 Reworked /BERR behavior
    - The /BERR line on the backplane connector is now the same that is
    going to the CPU; this means that external devices can detect when
    they access unmapped space when /BERR is asserted during bus mastering
    operation.
    Spare gate of open drain inverter was used to convert the active high
    bus error timeout to assert /BERR.
    [cpu-68000.kicad_sch, cpu.kicad_sch]
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2021-12-08 Mostly finished blinkenlights contraption
    - Added some headers that can have logic probes connected to them; we
    need to route them and ensure the pins are correct
    [backplane.kicad_sch, blinkenlights.kicad_pcb, blinkenlights.kicad_sch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]
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2021-12-09 Expose CPU function code on backplane
    - Routed the function code signals to the backplane; they're pulled to
    ground so that if a bus mastering device doesn't drive them the world
    won't explode (it will be a supervisor data access)
    [backplane.kicad_sch, cpu-68000.kicad_sch, cpu.kicad_sch]
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2021-12-12 Major cleanup of CPU board
    - A lot of traces got moved around to be less shitty
    - Routed a few more signals to the GALs so that we can eliminate some
    discrete logic, namely for function code checking. This is critical
    since we need to reduce path length when switching the backplane bus
    buffers for each bus transaction as quick as possible.
    - Actually provide a clock for the I2C master chip; it shares the clock
    with the audio chips, which is just a bit short of 8MHz.
    [backplane.kicad_sch, blinkenlights.kicad_pcb, blinkenlights.kicad_sch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]
2021-12-12 Replaced many B case caps with A case
    - There were sufficiently many 5V tantalum capcaitors on the
    blinkenlights board with the B case footprint (for 25V) rather than
    the A case (for 16V) assigned.
    [backplane.kicad_sch, blinkenlights.kicad_pcb, blinkenlights.kicad_sch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]
2021-12-12 Schematic cleanup and ERC fixes
    - Fixed many errors about duplicate or unassigned pins, and fixed some
    of the symbols and their pins directions.
    - More minor tweaks to the pcb.
    [backplane.kicad_sch, cpu-68000.kicad_sch, cpu.kicad_sch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]
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2021-12-14 Some more direct IOs for blinkenlights
    - /DTACK, /BERR, AS and R/W can be directly read/driven by Teensy GPIO;
    this should allow us to do bus transactions much faster since we can
    prepare the SPI transactions to set up the bus values, then control
    the bus timings most accurately.
    - Fixed up a few incorrect pin directions for symbols used in the
    blinkenlights board
    [backplane.kicad_sch, blinkenlights.kicad_pcb, blinkenlights.kicad_sch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]
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2021-12-30 Minor fixes for wrong parts
    - Mostly an incorrect fuse value and the wrong type of buffer on the CPU
    board buttons
    [backplane.kicad_sch, blinkenlights.kicad_sch, cpu-68000.kicad_sch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]
2021-12-31 Start of rev 2 board
    - This drops bus buffers, and replaces flash with DIP socketed versions.
    Also some minor tweaks to the board
    - Fixed power LED (D201) positioning
    - Fixed LED (too dark) for the right angle indicators
    [backplane.kicad_sch, cpu-68000.kicad_sch, cpu.kicad_sch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]
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2022-01-01 Finished rework of CPU card
    - All the busses are finished routing. The board is feature wise
    identical to rev 1, sans buffers, and with DIP boot ROM sockets rather
    than soldered flash.
    - Corrected a few remaining bugs on the board, namely the incorrect
    footprint for the +12V fuse.
    [backplane.kicad_sch, cpu-68000.kicad_sch, cpu.kicad_sch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]
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2022-01-02 Routed backplane mgmt board
    - Finished routing of the complete backplane management board; it
    doesn't do much other than provide power (with monitoring) and an
    audio output (with volume control) from the backplane.
    Originally this was gonna have a display but there's no space on the
    front panel for that.
    [Power.kicad_sch, backplane.kicad_sch, backplane_mgmt.kicad_pcb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]
2022-01-03 Created basic backplane board
    - Began schematic and routing for a basic backplane board; the slot
    alignments should be roughly correct and fit a 3U VME crate. It
    accepts a CPU card and management card, as well as up to six
    peripherals, and contains the required bus buffers.
    [Expansion.kicad_sch, Management.kicad_sch, backplane.kicad_pcb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]
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2022-01-05 Added audio mixer to backplane
    - Implemented mixing (via resistors and an op amp) for the audio outputs
    from each slot and CPU card. These inputs are tied to ground through
    weak pull downs, so peripherals can leave the pins open if they're not
    being used.
    It's possible that the resistance values for the mixer aren't quite
    correct and will produce a distorted mess with many peripherals
    outputting sound simultaneously; if that's an issue, we can adjust the
    value of the resistors or add per slot trimmers to adjust each slots'
    relative volume.
    [Audio.kicad_sch, Expansion.kicad_sch, backplane.kicad_sch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]
2022-01-05 More optimization of backplane
    - Fixed a few DRC errors and added LEDs with the spare IOs on the I2C
    expander.
    [Audio.kicad_sch, backplane.kicad_sch]
2022-01-07 Backplane mechanical improvements
    - Added screw holes to the backplane; they may or may not actually be
    correct but the spacing between them should be right. We've got holes
    every two HU's (2x .2") for extra spacing/material between holes
    - Added reset LED and some more pull ups
    - Minor tweaks to backplane management card
    [Expansion.kicad_sch, backplane.kicad_sch, backplane_mgmt.kicad_pcb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]
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2022-01-08 Finished routing relay board
    - Completed routing of the relay board; it's got added an address
    selector switch and an I2C expander that can be used to set the
    address automatically.
    - Minor tweaks to a few footprints, namely to make sure they're
    correctly tagged as through hole/SMD
    [Backplane.kicad_sch, relay-8ch.kicad_pcb, relay-8ch.kicad_sch]
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2022-01-09 Added missing screw holes to backplane
    - These apparently got removed at some point before the commit that said
    they were added got made, likely when updating the board from
    schematic. They were added back, though the X positioning may not be
    quite correct.
    [backplane.kicad_sch]
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2022-01-11 Tweaks to bill of materials
    - Added missing MPN's for a few components; tweaked a few bits of layout
    to increase some tolerances
    This includes kind of tweaking the boot rom socket positions in hopes
    of fitting fancier sockets
    [Backplane.kicad_sch, Power.kicad_sch, backplane.kicad_sch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]
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2022-01-12 Tweaks to backplane management board
    - Added pull downs to the audio inputs, so that if the backplane doesn't
    provide audio, the op amp inputs aren't floating
    - Minor tweaks to some of the routing. Also switched out the 5V
    regulator for a larger, easier to get version, and added some large
    planes for power dissapation.
    [Power.kicad_sch, backplane.kicad_sch, backplane_mgmt.kicad_pcb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]
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2022-01-14 Switched remaining pluggable screw terminals
    - Replaced the pluggable/replaceable screw terminals with CUI devices
    parts on the backplane (+12V/GND/+5V) and relay board (switched
    contacts) since they're much cheaper and basically the same thing as
    the corresponding WE/Phoenix Contact parts
    [Management.kicad_sch, backplane.kicad_sch, relay-8ch.kicad_pcb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]
2022-01-14 Removed GAL from relay board
    - Replaced the GAL on the relay board with some hard 74-series logic;
    this means the board needs zero "hard to get" parts.
    All the address decoding is done by a '688 magnitude comparison IC,
    which is LS logic so this board needs to consist of HCT logic to deal
    with its lower active high level.
    - Replaced 3D model for the hexadecimal rotary switches to one that has
    color :D
    [Backplane.kicad_sch, relay-8ch.kicad_pcb, relay-8ch.kicad_sch]
2022-01-14 Minor CPU board changes
    - Replaced the 5V analog regulator with a through-hole version that's
    easier to find given the current chip shortage. It doesn't need to
    supply a crazy amount of current so anything really goes
    - Moved some capacitors and cleaned traces up to better fit the fancy
    DIP sockets for the flash ROMs.
    [cpu-68000.kicad_sch, sound.kicad_sch]
2022-01-15 More CPU board tweaks
    - Cleaned up a few traces and replaced the MAX202 with a cheaper, easier
    to find part (SP232E) with a little bit of required PCB rework
    - Add 3D models for output polyfuses on power board
    [backplane_mgmt.kicad_pcb, cpu-68000.kicad_sch, peripheral.kicad_sch]
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2022-01-25 Replaced current sense with shunt+INA209
    - Instead of using unobtanium parts for the current sensing, we're
    instead just gonna use more of the shunt we already have to get for
    the current limit of the switching regulator, and then measuring the
    voltage drop with the INA209 which is functionally going to give us
    the same exact behavior as before.
    [Power.kicad_sch, backplane.kicad_sch, backplane_mgmt.kicad_pcb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]
2022-02-03 Minor layout tweaks across the board
    - Added an input for a test clock, and a jumper for sending this clock
    instead of the CPU clock to the clock pins of the expansion cards on
    the backplane boards
    - Reworked a bunch of the power supply board
    - Minor changes (to consolidate BOMs) on CPU board for some capacitors,
    they were replaced with SMD versions
    [Expansion.kicad_sch, Power.kicad_sch, backplane.kicad_sch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]
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2022-03-02 Minor tweaks based from assembly
    - Replaced the AT24CS32 EEPROMs with the AT24CS16 which is what was
    ordered. These are half the size, but use a totally different
    addressing scheme which needs to be followed. So, we should just
    standardize on these.
    The information stored in the actual EEPROM section (2KBytes in this
    part) will likely not be much larger than a small 32 byte (or so)
    header.
    - Removed a few redundant parts on the power management board, namely
    some resistors
    - Fixed the fucked footprint for the PTH08T220WAD module; the annular
    rings were way too small
    [Audio.kicad_sch, Backplane.kicad_sch, Expansion.kicad_sch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]
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

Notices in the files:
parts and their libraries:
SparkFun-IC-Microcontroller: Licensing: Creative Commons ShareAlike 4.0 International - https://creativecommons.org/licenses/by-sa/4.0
